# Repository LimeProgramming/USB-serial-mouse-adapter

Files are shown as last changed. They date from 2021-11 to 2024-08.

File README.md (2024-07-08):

# USB Serial Mouse Adapter
A USB to serial mouse adapter!
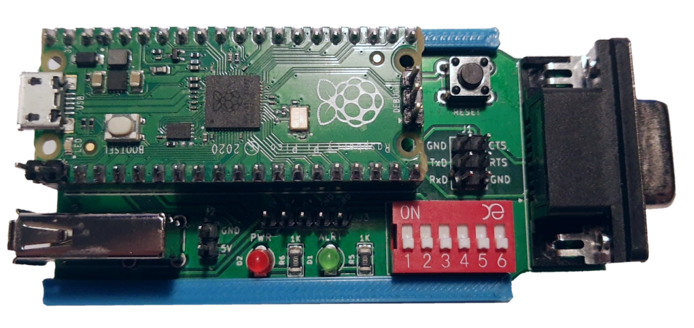
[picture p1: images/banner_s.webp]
ASSEMBLED_ADAPTER


## About
This project came about when I got my hands on an old 486 based PC. Having never really dipped my toes into retro computing, I didn't have an old serial mouse on hand. A quick eBay searched revealed that the decent ones cost a nice chunk of change that I didn't feel they were worth. Another search on Vogons revealed that some mad lads out there made active PS/2 to serial adapters using various micro controllers.  
Out of curiosity I examined how these worked and thought "Why can't I do this with a Pi Pico and USB mouse?" which kicked off this project. 

I hope it sparks your interest!
-Lime

## Features
With this adapter you can convert a modern native USB mouse to a classic serial mouse. That's right, native USB! No cheating by secretly using PS/2 compatible mice.
Want to use an optical mouse on a 386 running Wolfenstein 3D? Well now you can! Want to use a wireless optical mouse on a 486 running Doom? Well you might be able to! (depending on the mouse)

**Supported Protocols:**
- Microsoft Two Button
- Logitech Three Button
- Microsoft Wheel

**Unsupported Protocols: (May change based on demand)**
- Mousesystems
- Sun
- MM

### KVM:
Support for use on KVMs has been added as of version 1.1.1. 
It works fine on my **one**, startech branded, KVM that I have test with. Given that TinyUSB is a bit picky, your results may vary.

## PCBs
There are two variants of the PCB available in the KiCad folder, Phat and Slim for your preference. The main circuit for both PCBs is the same so the firmware package will work on both PCBs. A full BOM for LCSC (except for header pins) is available in the Phat folder: [LCSC BOM](https://raw.githubusercontent.com/LimeProgramming/USB-serial-mouse-adapter/main/KiCad/Phat/BOM_LCSC.xls). For the Slim build you can omit the dip switches and reset switch (you will have to source an appropriate SMD reset switch).

### Building a PCB:

#### MAX232/3232 voltage selection:
The PCB has a jumper to select between 3.3v and 5v for the MAX chip. 
- If you're using a MAX232 then bridge 5v to the center pin and install all the resistors. The part listed in the [BOM](https://raw.githubusercontent.com/LimeProgramming/USB-serial-mouse-adapter/main/KiCad/Phat/BOM_LCSC.xls) is a MAX232 chip.
- If you're using a MAX3232 then bridge 3.3v to the center pin, bridge R4 and R3, and remove R1 and R2.

#### Board to Pico USB data connection:
The `TP2` and `TP3` testpoints on the board must be soldered to the corresponding `TP2` and `TP3` test points on the Pico, underneath the USB connector:

[Pico bottom TP2 and TP3 test points](images/Pico_bottom.png)

### Phat:
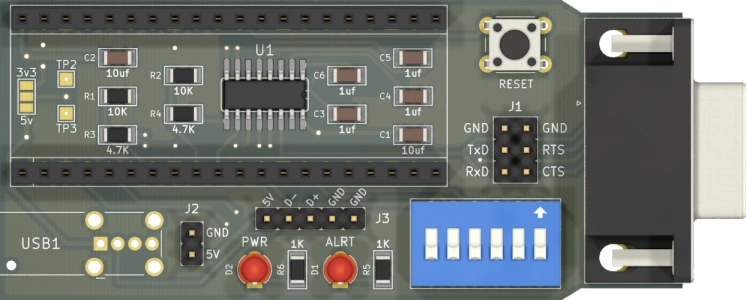
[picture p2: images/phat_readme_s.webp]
PHAT_PCB
[](https://raw.githubusercontent.com/LimeProgramming/USB-serial-mouse-adapter/main/images/phat_readme.png)

Also known as the original design.
This PCB is the version I had made with the mindset of it being the default/one and only. 
| Differences | Silkscreen | Description |
|:--:|:--:| :--:|
| Serial Pin Header | J1 | Intended to use with a serial breakout cable |
| USB Pin Header | J3 | Intended to be used with motherboard USB breakout cables |
| Dip Switches | SW1 | Quickly and easily configure the adapter |

#### Phat Cases:
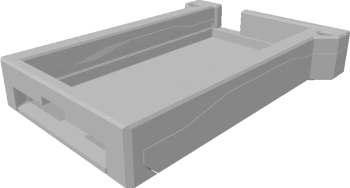
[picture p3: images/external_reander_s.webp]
externalcase
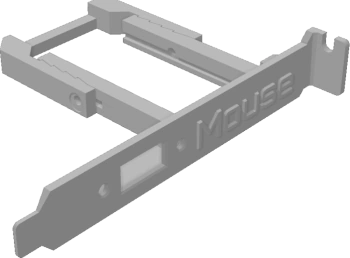
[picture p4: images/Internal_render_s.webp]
internalcase
[](https://raw.githubusercontent.com/LimeProgramming/USB-serial-mouse-adapter/main/images/external_reander.png)[](https://raw.githubusercontent.com/LimeProgramming/USB-serial-mouse-adapter/main/images/Internal_render.png)

### Slim:
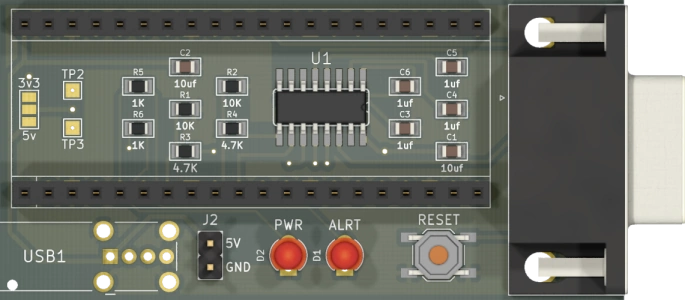
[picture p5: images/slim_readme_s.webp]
SLIM_PCB
[](https://raw.githubusercontent.com/LimeProgramming/USB-serial-mouse-adapter/main/images/slim_readme.png)

Made for people be require the adapter to be as small as possible. Not much wider than the serial port itself. 

## Powering the device
### MicroUSB:
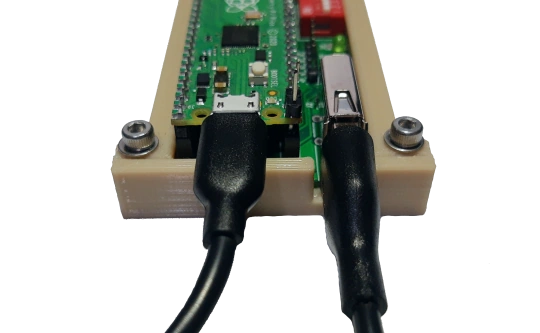
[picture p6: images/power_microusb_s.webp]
POWERING_MICROUSB
[](https://raw.githubusercontent.com/LimeProgramming/USB-serial-mouse-adapter/main/images/power_microusb.png)
The easiest way to power the device would be to use the Pico's micro USB port. Be sure to use a USB power only cable or a wall power adapter otherwise it won't pick up the mouse.

**PLEASE NOTE:** Some "power only" USB cables have the data lines shorted together. You can test if this is the case by plugging the cable into the Pico and using a meter to check for continuity between `TP2` and `TP3` on the Pico. If there is continuity you have a cable like this. Cut the data lines on a normal USB cable as an option.
<br clear="left"/>

### Power-In Header:
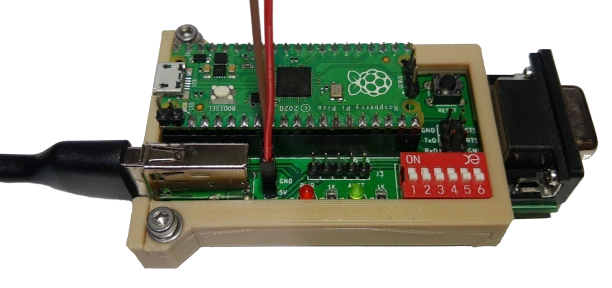
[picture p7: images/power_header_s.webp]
POWERING_HEADER
[](https://raw.githubusercontent.com/LimeProgramming/USB-serial-mouse-adapter/main/images/power_header.png)
Both the Phat and Slim PCB's feature an 5 volt power in header. You can use this creatively to power the adapter, even from the PC itself perhaps? Personally I'm connecting it to a wall power supply to give a more secure connection than MicroUSB.
<br clear="left"/>

### Other ways:
There is nothing stopping you from powering the device using a powered OTG cable or a hacked up USB extension lead. The device itself needs about 100 milliamps so as long as you get it that power, it'll run away happily!

## Configuration

The adapter has quite a few settings available and these settings are stored on micro controllers flash memory. 
It will remember your settings between uses and the same settings carry between different computers and even firmware upgrades (unless otherwise state in a changes log)

There are two primary ways of editing the settings of the USB-2-232

### Headers
The phat variant of the PCB includes headers in either of the form of dip switches or jumper headers. While not super configurable they do give quick access to some handy settings. The headers can be set while the micro controller is on with changes being applied in real-time or they can be set while the micro controller is off with changes being applied next time the controller is booted.

| Num | Setting |
|:--:|:--:|
| 1 | Three Button Logitech Protocol |
| 2 | MS Wheel Protocol |
| 3 | 75% Mouse Travel Modifier / Dip 3 + 4 for 25% |
| 4 | 50% Mouse Travel Modifier / Dip 3 + 4 for 25% |
| 5 | 7N2|
| 6 | 19200 Baud Rate|

### Serial Terminal
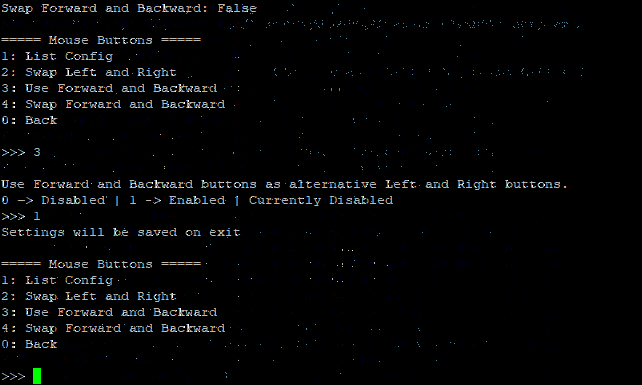
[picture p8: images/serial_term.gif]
serial terminal gif


Both the phat and slim variants of the PCB support being configured via serial terminal. The serial terminal allows for more advanced configuration of the mouse adapter. Any additional settings added in a software update will be available here.
The serial terminal has been translated to German, images available in both German and English as default langauge.  

### Serial Terminal Options
+ Mouse Travel
    + List Config
            | List the current mouse travel settings
    + XY Travel 
            | XY mouse travel modifier 1% -> 200%
    + X Travel
             | X (Left and Right) mouse travel modifier 1% -> 200%
    + Y Travel 
            | Y ( Up and Down) mouse travel modifier 1% -> 200%
    + Invert X
            | Invert X (Left and Right) mouse movement.
    + Invert Y
            | Invert Y (Up and Down) mouse movement.
    + Movement Type
            | Set Movement Type. USB mice talk faster than serial mice, movement type decides what to do with the backlog between serial mouse updates.
        + Additive: 
                | Sum the mouse movement (Sensitive)
        + Average
                | Avg the mouse movement  (Insensitive)
        + Coast 
                | Send the mouse movement incrementally (Slippy)
    + Cosine Smoothing
            | Makes the cursor proportionally less sensitive at high speeds, leaving the movement mostly one to one at low speeds

+ Mouse Buttons
    + List Config
        | List the current mouse button settings
    + Swap Left and Right
        | Swap the left and right mouse buttons
    + Use Forward and Backward
        | Use the mouse forward and back buttons as alternative left and right buttons
    + Swap Forward and Backward
        | Swap forward and back buttons if they are being used as alternative left and right buttons
+ Serial Settings
    + List Config
        | List the current serial settings
    + Format
        | One stop bit (7N1) or two stop bits (7N2) 
    + Baud Rate
        | 1200 2400 4800 9600 19200 Baud Rates. Note you will need compatible mouse drivers.
     + Mouse Type
     | Microsoft 2 Button, Logitech Three Button or Microsoft Wheel mouse. Note: You may need to reconfigure your mouse driver upon change.
+ Firmware
    + Information | Information about the firmware
    + Language | Set the language of the settings terminal
    + Reset | Reset mouse settings back to default
    + List Default Settings | List the default settings of the adapter
+ Exit
    + Return to mouse mode

### Accessing the terminal
You can access the serial terminal in one of two ways:

#### Method 1: Serial Terminal Emulator
You can open a serial terminal emulator (like kermit) on the computer you have the mouse connected to, connect to the same com port the mouse driver is using and press the enter key.
```
Baud Rate: User Set
Data Bits: 7
Stop Bits: User Set
Parity: None
Flow Control: None
```
#### Method 2: USB to TTL
You can also connect the unused UART of the Pi Pico with a cheap USB to TTL device or even another Pico running the picoprobe firmware. Open your favorite serial terminal emulator (like putty) connect to the TTL device and tap the enter key. 
```
Baud Rate: 115200
Data Bits: 8
Stop Bits: 1
Parity: None
Flow Control: None
```
Connecting to the adapter in this way will allow you to change settings regardless of the adapter being connected to a PC or not. 
The unused UART of the pico can be accessed from the top two pins between the full size USB port of the PCB and the micro USB port of the Pico.

### Resetting the adapter
Forgot your settings and can't get the adapter working? Don't worry.
There are three different ways to reset the adapter:

#### --- Serial Terminal
As written above, you can reset the adapter back to default settings from the terminal. You can connect to the unused UART of the pico regardless of the settings of the mouse. 

#### --- Small Flat Head Screwdriver
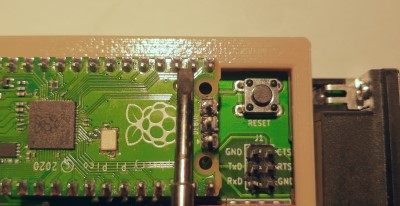
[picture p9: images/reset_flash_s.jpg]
RESETTING_FLASH
[](https://raw.githubusercontent.com/LimeProgramming/USB-serial-mouse-adapter/main/images/reset_flash.jpg)

**How To:**
1. Press a small flat head into the position shown above.
2. Power on the adapter and the Picos built-in LED will glow solid.
3. Hold the flat head in position for two or three seconds for the Picos LED to start blinking.
4. Once it is blinking, you can let go of the GPIO and press the reset button.
5. The adapter will boot up with default settings.
#### --- Nuke UF2
**How To:**
1. Download the [flash_nuke.uf2](https://datasheets.raspberrypi.com/soft/flash_nuke.uf2) file.
2. Connect the adapter to your PC using the microusb port built into the Pi Pico.
3. Hold Reset, then bootsel, then release reset then bootsel. This will make the Pico appear as a removable storage device. 
4. Drag the flash_nuke.uf2 file to the storage device. This will reset the flash the on the Pi Pico.
5. The Pico should reboot on its own and show up as a removable storage device again. If it doesn't, tap the reset button.
6. Download the latest firmware and drag that UF2 file to the storage device.
7. The adapter will boot up with default settings.

# Compiling the Firmware
The default mouse settings can be edited in `default_config.h` prior to compilation. You can use this to set the mouses default settings for your own configuration. 

The build environment is a normal PicoSDK setup, there are several guides out the for both Linux and Windows.  From experience the setup is easier in Linux. However there is one important thing you need to know:

**PicoSDK Version 1.5.1**
Previous Versions of this project required a customized version of TinyUSB, since then TinyUSB has implemented improved USB HUB and Hosting functions so the customized TinyUSB is no longer required. 
However, TinyUSB version 16 is recommended for the scroll wheel to work more reliably. 

# Known Issues
**USB Hubs**
Due to the pico having a USB 1.1 host or TinyUSB not using hubs correctly, this project struggles with hub compatibility. 
A hub which should work but I have not texted can be found here: https://www.olimex.com/Products/USB-Modules/USB-NeoHub/open-source-hardware 

Personally I use an amazon basics 4 port USB2.0 hub and it works perfectly.

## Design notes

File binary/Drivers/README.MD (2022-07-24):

# Modified Mouse Drivers
Modified serial mouse drivers which support higher baud rates.

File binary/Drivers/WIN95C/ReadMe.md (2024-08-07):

# Windows 95 
### Driver version: 4.0.0.950
**Supported Baud rates**
 - 1200
 - 2400
 - 4800
 - 9600
 - 19200
 
**How to install:**
 1. Drop VMOUSE.VXD of your desired baud rate to the following folder c:\windows\system\vmm32.
 2. Reboot and set your serial mouse adapter to your desired baud rate.
 
**Important**
To change the VMOUSE.VXD file for another speed you'll need to use a bootdisk of some kind. Not sure if DOS mode will work.

Enjoy.

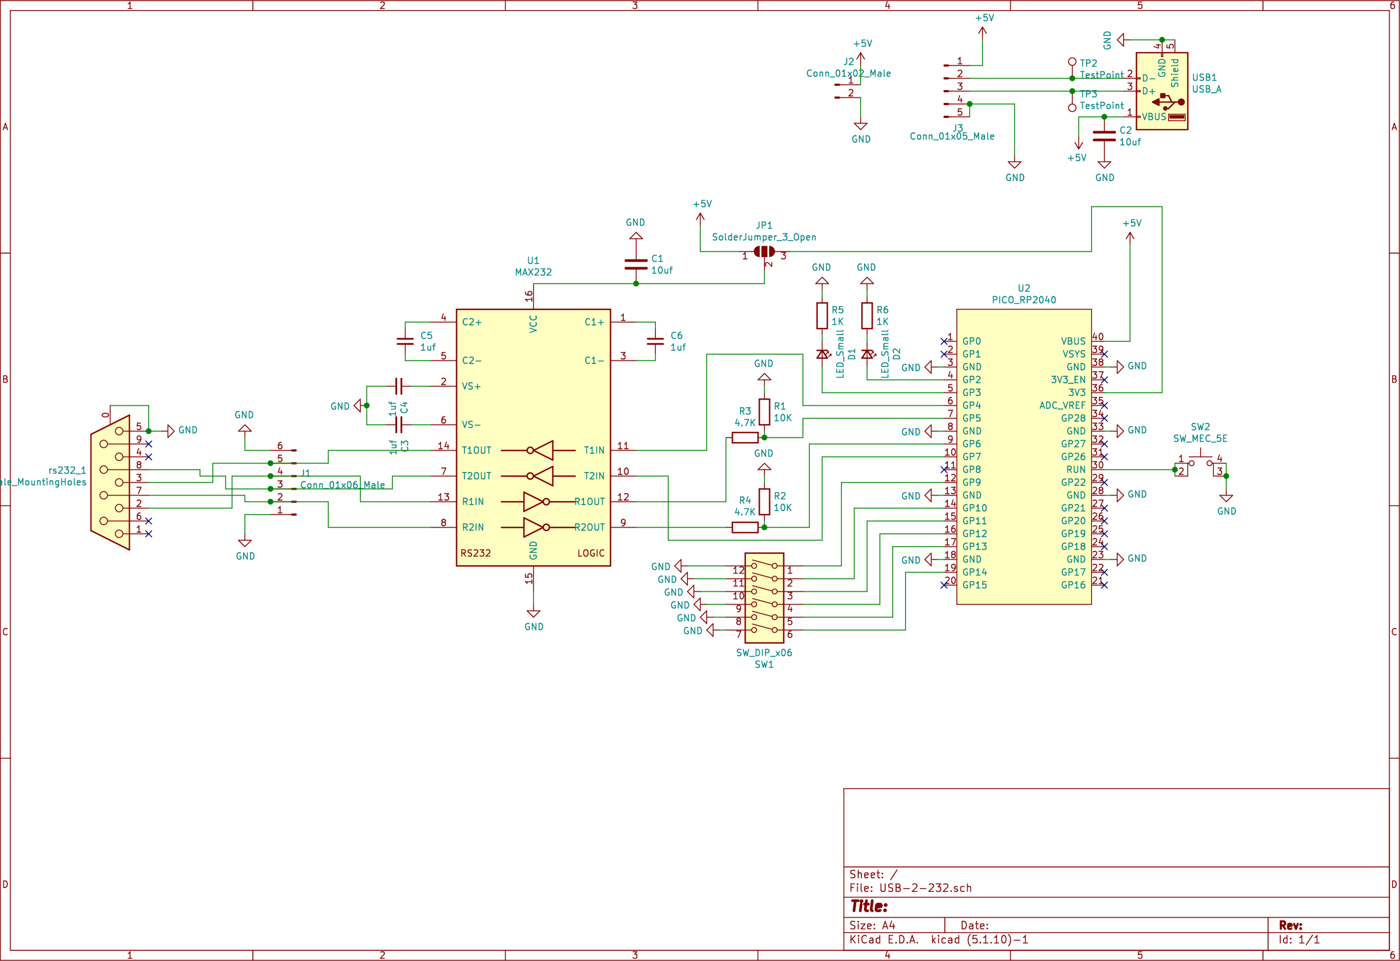
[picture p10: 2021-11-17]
images/Schematic.png

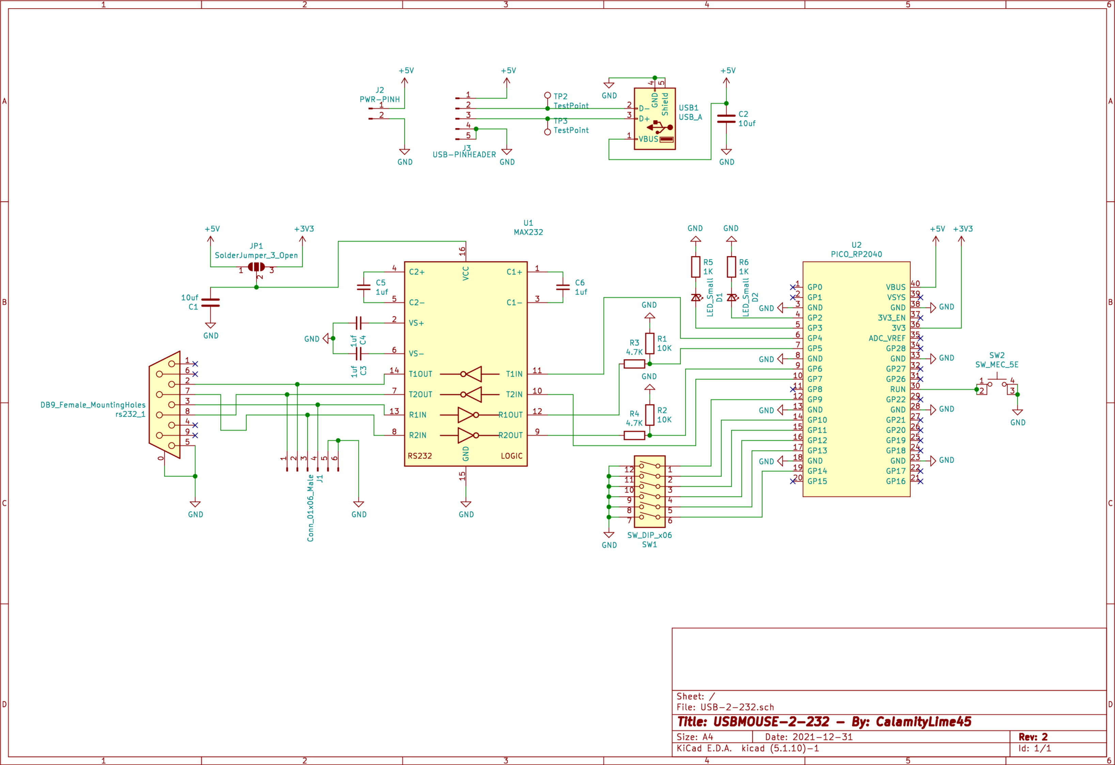
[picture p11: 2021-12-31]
KiCad/Phat/images/Schematic.jpg

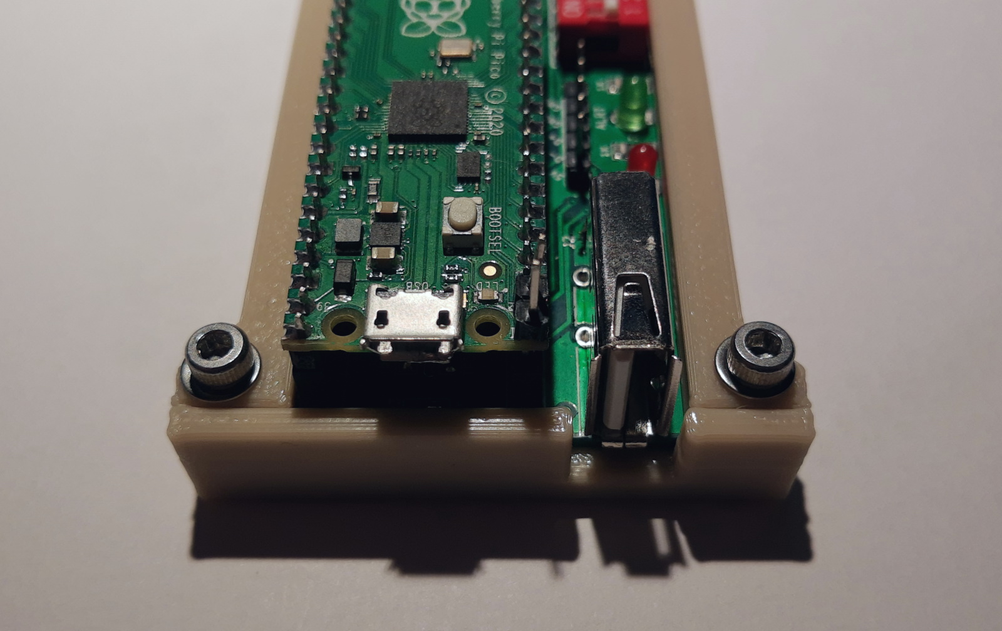
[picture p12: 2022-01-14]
images/Case-External-1.jpg

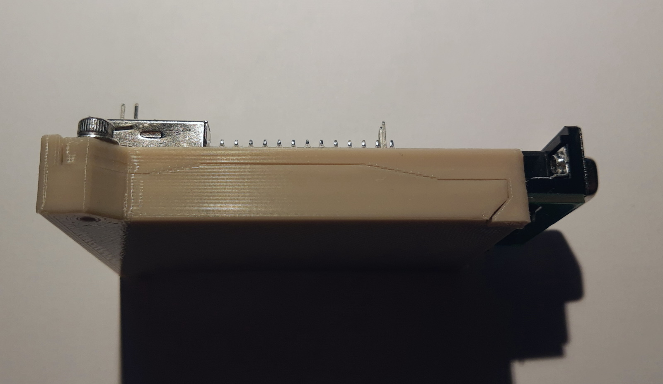
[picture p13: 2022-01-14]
images/Case-External-4.jpg

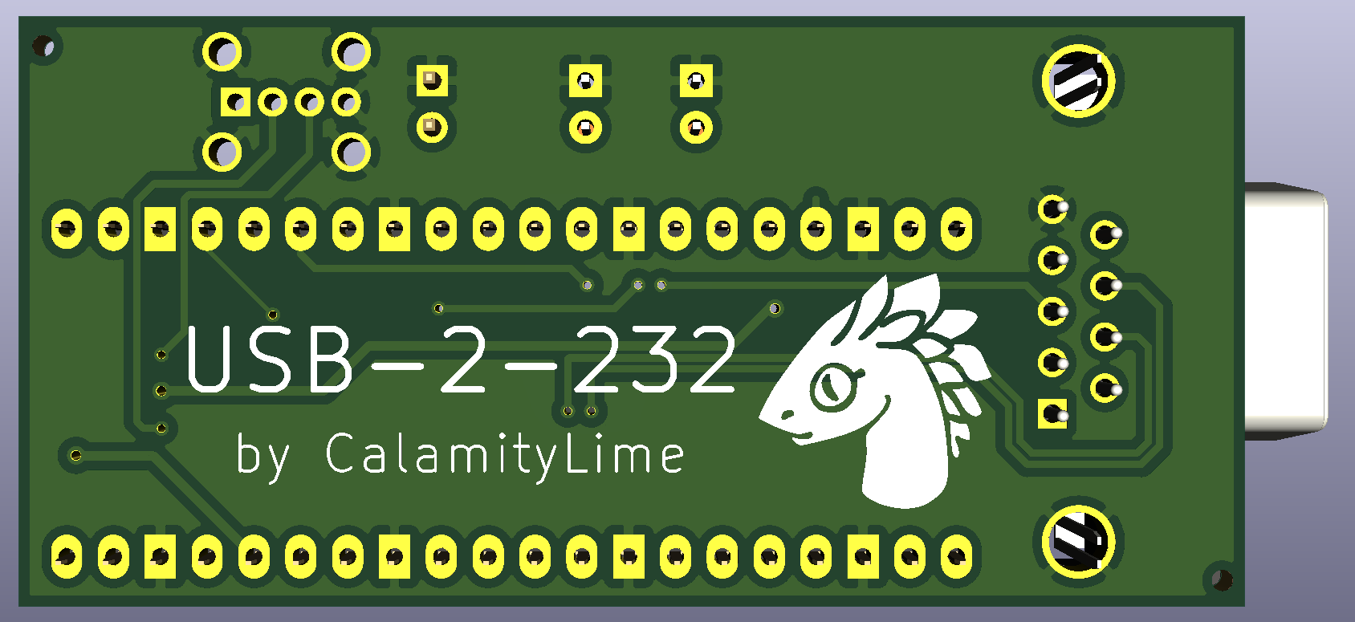
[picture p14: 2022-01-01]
KiCad/Slim/images/render_back.PNG

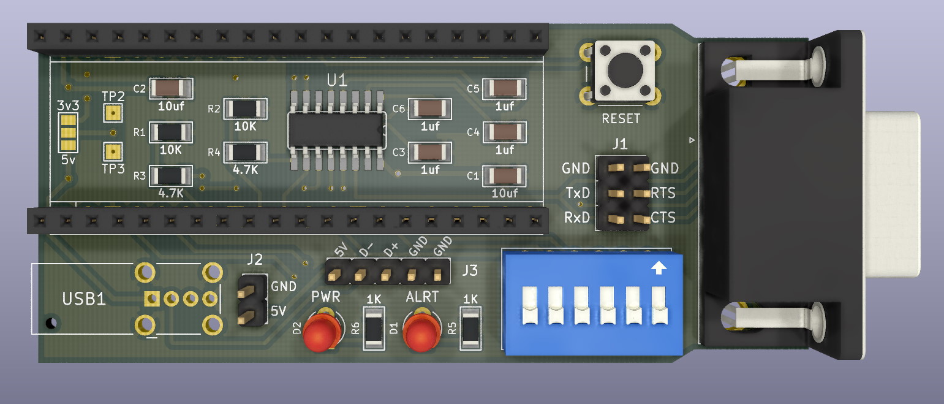
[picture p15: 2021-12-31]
KiCad/Phat/images/render_front.jpg

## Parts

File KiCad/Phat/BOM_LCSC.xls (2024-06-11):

LCSC Part Number | Manufacture Part Number | Manufacturer | Customer NO. | Package | Description | RoHS | Order Qty. | Min\Mult Order Qty.
C13585 | CL31A106KBHNNNE | Samsung Electro-Mechanics |  | 1206 | 50V 10uF X5R Â±10% 1206 Multilayer Ceramic Capacitors MLCC - SMD/SMT ROHS | YES | 20 | 20\20
C1848 | CL31B105KBHNNNE | Samsung Electro-Mechanics |  | 1206 | 50V 1uF X7R Â±10% 1206 Multilayer Ceramic Capacitors MLCC - SMD/SMT ROHS | YES | 50 | 50\50
C17902 | 1206W4F1002T5E | UNI-ROYAL(Uniroyal Elec) |  | 1206 | 250mW Thick Film Resistors 200V Â±100ppm/â„ƒ Â±1% 10kÎ© 1206 Chip Resistor - Surface Mount ROHS | YES | 100 | 100\100
C17936 | 1206W4F4701T5E | UNI-ROYAL(Uniroyal Elec) |  | 1206 | 250mW Thick Film Resistors 200V Â±100ppm/â„ƒ Â±1% 4.7kÎ© 1206 Chip Resistor - Surface Mount ROHS | YES | 100 | 100\100
C4410 | 1206W4F1001T5E | UNI-ROYAL(Uniroyal Elec) |  | 1206 | 250mW Thick Film Resistors 200V Â±1% 1kÎ© 1206 Chip Resistor - Surface Mount ROHS | YES | 100 | 100\100
C26860 | MAX232ESE+T | Analog Devices Inc./Maxim Integrated |  | SOIC-16 | 120Kbps transceiver 2/2 SOIC-16 RS232 ICs ROHS | YES | 10 | 1\1
C141882 | D-DMR009PF-D002 | Ckmtw(Shenzhen Cankemeng) |  | Push-Pull | 9P Female D-Sub Right-Angle 2 3A -50â„ƒ~+105â„ƒ Push-Pull D-Sub / VGA connector ROHS | YES | 10 | 5\5
C962227 | KH-BM2.54-6P | Shenzhen Kinghelm Elec |  | Plugin | 6Bit 24V Red 100mA 2千次 Slide (Standard),凸起式 Plugin DIP Switches ROHS | YES | 7 | 7\7
C26235 | USB-AF | Jing Extension of the Electronic Co. |  | Plugin | USB 2.0 1 4P Female Type-A Plugin USB Connectors ROHS | YES | 5 | 5\5
C85161 | 204-10SYGD/S530-E3 | Everlight Elec |  | Plugin,D=3mm | Green-yellow 3mmåœ†å½¢ç ¯å¤´ Plugin,D=3mm Light Emitting Diodes (LED) ROHS | YES | 20 | 20\20
C330748 | TJ-L3FYTGHRMBCSFLC4R-A5 | TOGIALED |  | Plugin,D=3mm | Red 3mmåœ†å½¢ç ¯å¤´ Plugin,D=3mm Light Emitting Diodes (LED) ROHS | YES | 20 | 20\20
C5274846 | YTS1R0012DBT00 | YIYUAN |  | Plugin,6x6mm | 6mm 6mm 50mA Round Button Straight SPST 6mm 250gf 12V Plugin,6x6mm Tactile Switches ROHS | YES | 20 | 20\20

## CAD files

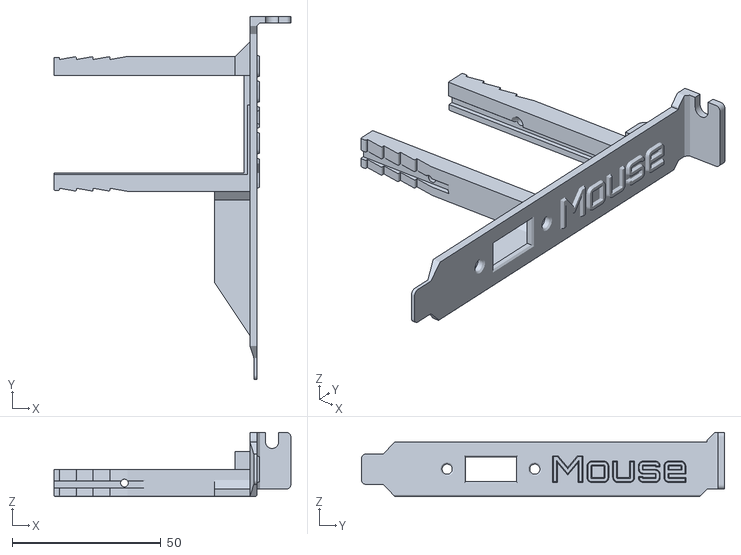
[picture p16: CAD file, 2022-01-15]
cases/Phat Board/Internal/Case-Internal-Sled.stl
79.7 x 122.2 x 21.6

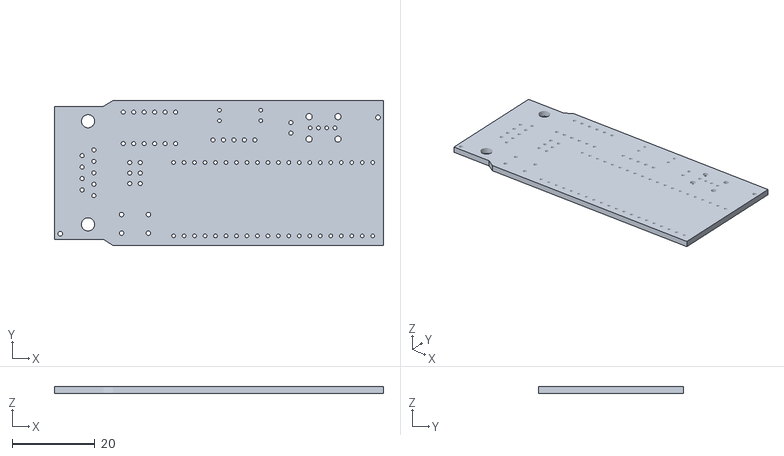
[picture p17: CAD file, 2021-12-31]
KiCad/Phat/USB-2-232-USB-2-232Pcb_1509.stl
79.7 x 35.1 x 1.60

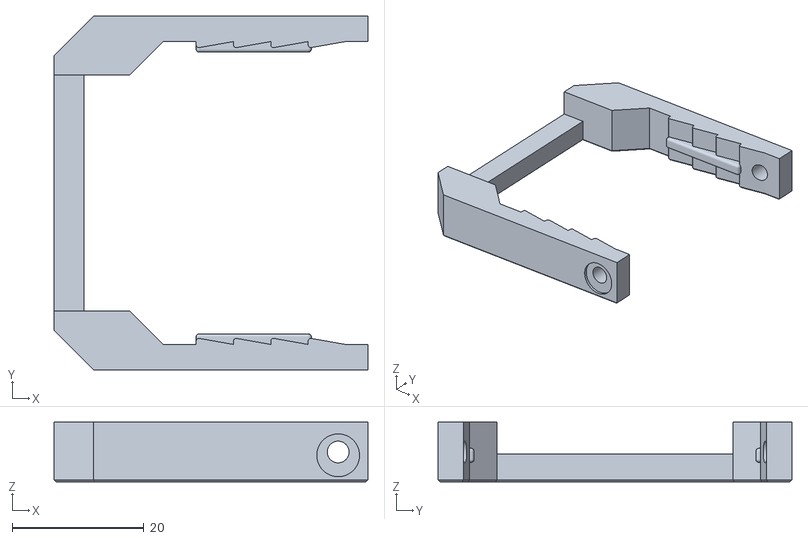
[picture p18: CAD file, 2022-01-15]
cases/Phat Board/Internal/Case-Internal-Lid.stl
47.6 x 53.8 x 9.11

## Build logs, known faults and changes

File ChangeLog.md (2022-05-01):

# Change Log

## Version 1.0.0
Initial Release.

## Version 1.1.1
- Added KVM and USB hub support
- Added different mouse movement types
- Added "cosine mouse smoothing"
- Small bug fixes
- Latest version of the Pico-SDK
- Latest but modified version of TinyUSB

## Version 1.2.2

- Modified terminal code to be easier to translate.
- German language translation added to serial terminal.
- Multi-core Processing. The Pi Pico has two cores baked into it so might as well use them. The second core is currently dedicated to transmitting the serial mouse data over UART and the first core is dedicated to handing the USB mouse, plus the serial terminal. This should keep the report rate consistent while keeping lag to a minimum.
- Flash wear leveling for saving configuration. Should extend the life of the Pico 200 fold.
- Added Support for 19200 baud rate.
- Changed the Dip Switch 6 to toggle between 19200 and 1200 baud rates.
- PWR LED now flashes while the adapter is in serial terminal mode.
- While adapter is in serial terminal mode changes to the dip-switches are ignored. This was an easy way to ruin your day before!
- Changed how Coasting movement type worked. Should feel the same but work more consistently.

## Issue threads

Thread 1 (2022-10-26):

Cant make it work

shaeon, 2022-10-26:
First of all, thank you for the project, I think it's amazing.

I had order some boards from China with the components and the rest of things I bought by internet without problems.

The first problem was that in the readme there is no documentation about the soldering point to choose 3.3V or 5V.  Looking at the schematic and some pictures I thought I should connect 5V to the center pin. That finally let me access to serial terminal.

The problem is that I can't get the mouse to work. I have tried on modern and old computers, Even I got a db9 serial mouse that works in all computers but the usb-serial-mouser-adapter doesn't work.

The only thing was that the first time I plugged it without the soldering point, but I don't think it was damaged or anything. Maybe I'm wrong and need to solder to the 3.3V and I fried a pi pico.

I did the following test, I opened a terminal with my real serial mouse and at the top when I move the mouse I get information (strange chars mark with red line). If I swap real mouse to the usb-to-serial converter (powered by a wall charger) I get nothing on screen, but if I invoke the menu it does come up.

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

What could it be?

LimeProgramming, 2022-10-26:
Ah, I had to re-read the read-me. I must have completely forgotten about the jumper.

It was very much just an early idea that stuck around. The jumper is for the max232. If you're using a max3232 then you bridge 3.3v to the center pin and bridge R4 and R3, and remove R1 and R2 (This was my first real PCB and it made sense to me at the time to do it that way)
If you're using a max232 then you bridge 5v to the center pin and install all the resistors.

I made it that way because technically using a max232 is out of spec and it should use a max3232 however the max3232 costs more, is potentially less compatible with host machines. and the basic part and cheaper max232 from JLC works just fine and is within tolerances.

Due to changes in the firmware the ALRT LED is really a mouse LED. It should light up when a usb mouse in connected to it. If it doesn't that means something else is on the USB line. In testing with others, usb wall power bricks connected to the microusb port can stop the pico from picking up the mouse.

You can solve this by a few ways:
- Using a USB brick that doesn't have data connections
- Using a USB cable that doesn't have data connections, (mine didn't, it was supposed to but it seems that they were broken) IF you're feeling up for it, you can cut into a usb cable gently and just cut the white and blue wires inside it. Sometimes really cheap ones for charging phones lack the data lines.
- Powering it via the pin headers.

I also believe that you can use an USB OTG with the extra connection for power. I believe so, I haven't used one myself.

Sorry about that. I never thought at the time about this issue. I have been working on a new edition of this board that's powered differently to fix this issues. I just never backported it since I didn't think people were interested in this project.

Also, those weird characters on top of putty print out, that's just the mouse movement data. It;s what your driver usually see's

I hope that helps.
If you're interested, there is a thread on vogons about this project that might help. I've documented a lot there while working on this, if something is missing from the readme here, it would be somewhere there.
https://www.vogons.org/viewtopic.php?f=46&t=84280

-Lime

shaeon, 2022-10-27:
I did order to JLC with your gerbers, bom list, all! It was so easy :)

4 person (some friends) ask me about this adapter, because the serial mouse became be so difficult to get. I discovery what's wrong looking scheme and photos at vogons.org web.

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

I didn't solder wires between usb D+ D- line from pcb to pi pico. Again i didn't read that on readme. I'll test it tomorrow because because I have board at work. I'll tell you them.

Thanks for your help / support. :)

LimeProgramming, 2022-10-27:
Wow I forgot about those wires myself.

I'm going to have to update the read me with an assembly section.
Again, Sorry about that. I also have a firmware update that I have to push out but I'm messing with drivers at the moment. You might have read on Vogons that I want to get higher baud rates working on win95, I don't know how possible that actually is though but we'll see. There has also been an update to TinyUSB and it behaves much nicer with hubs and multiple devices present (most of the time anyway)

You just have to solder TP2 on the PCB to TP2 of the pico, TP3 of the PCB to TP3 of the pico.

Let me know what you use this for, I'm very curious what people would want these for.
-Lime

shaeon, 2022-11-02:
Hi Lime!

I solder the two D-,D+ usb lines but i cant still make it works. I think i'm loosing something. Even I tried do nuked and after load again firmware 1.3.2. Maybe i need try another version?

I tried: Two different boards with 3 different usb mouses, in 3 different computer, but i cant get light in "alarm" light when i plug mouse, so I think this is the big problem.

My boards come with almost solders from JLC (even cheap max232). I just got your gerbers and bom and upload. I test line from usb with tester and i have line in pinheader J3, 5V and GND.

What i can test it more?

We'll use in old computer, because old serial mouse became more hard to make it work.

Best Regards.

LimeProgramming, 2022-11-02:
I tried nuking one of my boards, loaded the firmware 1.3.2, plugged in a usb mouse and it worked.
I cut open the usb cable to cut the white and green wires for reasons I said in my first reply.

You are getting a power LED aswell yeah? it's not a case of just soldering in the leds the wrong way. The power led comes on when the device has power and it blinks to tell you it's in serial terminal mode.

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

LimeProgramming, 2022-11-02:
As you can see, the ARLT led lit up without the serial port being connected to anything.

The mouse is a standard microsoft mouse and this adapter has worked with every usb mouse I tried.

Does this image help at all?

You can ignore the black jumper above the green led, I didn't notice it before taking the picture. It's not doing anything.

shaeon, 2023-02-20:
I did a lot of test, i think maybe my wire is thin but change mouse (one that work on mist) and power by duponts work perfect! :)

I'm sorry be so late answer you. Thanks for your support.

I close this issue. (very happy!)

Closed 2023-02-20.

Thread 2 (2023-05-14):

BOM in plain text for both PCBs?

KenjiUmino, 2023-05-14:
I would like to build the slim version of this adapter, but I could not find a bill of materials list - until I looked into the KiCad files for the phat PCB and found a "BOM_JLCSMT.xls" that I had to download before I could view it.

This file seems to be for the slim PCB as it does not include the switch block.

It would be nice to have a BOM for both PCBs in plain text so it is viewable from the webbrowser.

LimeProgramming, 2023-05-16:
Hello there

The slim PCB doesn't have the switch block at all. Honestly even though at first I was very amendment about the switch block being a requirement for ease of use, I use the terminal to configure the adapter.

Fair point. I saved the BOM and CPL in normal excel file formats just to stop a popup when I saved the file in excel.
I should be able to just add a readme in the folders.

I hope you enjoy the adapter.

KenjiUmino, 2023-06-04:
Hi Lime,

thanks a bunch for looking into it

> I saved the BOM and CPL in normal excel file formats just to stop a popup when I saved the file in excel.
> I should be able to just add a readme in the folders.

Thanks for looking into it - I have not finished the adapter yet, which might be a good thing, as I found out I might get it done cheaper than expected.

I originally planned to order the slim PCB at some PCB place, but in another futile attempt to organize the mancave, I found out that I have way too many of these small green proto boards than I know what to do with and it looks like they are just big enough to fit everything (including the jumpers for configuration) while the whole thing would be about the same size as a slim PCB.

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

Closed 2023-06-04.

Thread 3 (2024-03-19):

PCBWay details

Fachher, 2024-03-19:
Hi. I would like to thank you for your great work. Could you please provide all information required by PCBWay, so that they can make it.

Number of Layers, Dimension, FR4-TG, Thickness, Hole size, Surface finish, Finished copper.

https://www.pcbway.com/orderonline.aspx

Thank you in advance for your help.

sweetlilmre, 2024-06-24:
I'm pretty sure that if you just upload the gerbers and use the defaults you'll be fine. Are you wanting PCBWay to do the assembly as well? My suggestion would be to use JLC for the boards and LCSC for parts, it's much more cost effective if you build it yourself.

Fachher, 2024-06-24:
Hi @sweetlilmre thank you for your answer. Adam recommended JLC to me as well. Boards have been manufactured in the meantime. If I find the time, I will try to assemble the components on the board. Btw would it have been possible for JLC to assemble the board for me?

sweetlilmre, 2024-06-24:
It would have, but not worth it in my opinion. With the 1206 footprint of the SMD components, soldering it yourself should be fairly easy. Only complex chip was the MAX232 but even that wasn't too bad.

LimeProgramming, 2024-06-25:
this board was meant to be hand soldered which is why i used very large components. I didn't know how the SMT services worked and I had enough to figure out in this project at the time.

and since it kinda looks like I just ignored this issue, they emailed me and I talked to them via email.

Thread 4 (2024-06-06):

LCSC / JLCPBC parts

sweetlilmre, 2024-06-06:
In #2 a user is asking for the complete BOM list, specifically required is the DB9, dip switch block, USB A socket.
Could you provide these? A full BOM with everything: LEDs etc would be appreciated.
I have looked at LCSC and found these part numbers which may work:

DB9: C141882
DIP Block: C5299507
USB Socket: C720524

LimeProgramming, 2024-06-08:
Parts your picked should work fine, but here's what I used.

DIP 9: C141882
USB socket: C26235
Dip block: C962227

LED's are LED's, pick your favourite colors and enjoy.

I feel like this project has gotten far more interest than I thought it would, especially in the last 2 or 3 weeks. Did something happen?

sweetlilmre, 2024-06-09:
Thanks for the confirmation. I ordered the parts I'd selected, so I'm glad to know they'll work!
As far as interest, I found the project after making some of necroware's PS2 to serial adapters and trying to improve the firmware by looking at other code. I have a feeling your project might have been mentioned on the PicoGUS discord some time back but can't be sure, so that might have spurred interest. At any rate, it's an awesome solution and I can't wait to build some boards, thank you!

LimeProgramming, 2024-06-09:
Ah I see.

fair enough so. Good luck with them. TinyUSB at least last I looked at it was a buggy mess, so the adapter is very picky with hubs and it doesn't like unplugging and replugging the usb mouse.

But it does work when it's working.

I did include modified serial mouse drivers for DOS in the repo, thought I had included the modded drivers for windows 9x as well but doesn't seem like I have, no idea where those have gone now. I remember trying to make a bootdisk that installed the drivers automatically and it worked fine for english installs but no other languages because it tried to find the version of windows you were using from the license file.

Still, thanks for the interest and enjoy.

Closed 2024-06-23.

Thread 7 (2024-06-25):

No Power To Mouse

oXL0C0Xo, 2024-06-25:
Hoping that someone here can help me. When plugging in a USB optical mouse (Intellimouse Optical USB), I haven't been able to get the laser on the mouse to light up no matter what I try.

I have tried different USB cables (about 15 of them), also powering the device via the 5v header straight from the power supply, nothing seems to get this mouse to light up.

I can access the serial configuration tool, so I know that it is connected. If I plug the mouse into my personal computer, it powers right up and I can use it, so I know that it is good.

I have used a max232, and the 5v bridge is in place.

The strange thing is that this is the second adapter I have built, as I was having the same issue with the previously built one.

Any Ideas would be greatly appreciated. Thanks!

sweetlilmre, 2024-06-25:
Have you soldered TP2 and TP3 on the board to the TP2/TP3 points on the Pico? I'm facing similar issues and trying to debug (I had the laser blinking, but only went stable after that, although the adapter is still not working). This closed issue has some detail: #1 

I have a pending PR to update the docs.

oXL0C0Xo, 2024-06-25:
I had not done that, but I just tried it and it doesn't seem to make a difference

oXL0C0Xo, 2024-06-25:
Some more information... if I have all of the switches set to "off" it detects the mouse when I boot, and loads the driver (the mouse still doesn't power up). If I then try to access the serial config using kermit, nothing comes up. If I then set switch 6 to "on", I can connect to the device config, and the power light starts flashing.

The weird thing is that if I leave switch 6 set to "on" and reboot the system, it no longer detects the mouse.

Regardless, I should be able to just plug this into a USB brick on the wall, and when I plug my mouse in it should power up without needing to be connected to a computer via serial correct?

sweetlilmre, 2024-06-25:
AFAIK yes, my mouse does power up. Maybe try another mouse if you have one available, and failing that I guess double check everything and use a meter to test voltages? Sorry I can't be more help. If I find something I'll ping back.

LimeProgramming, 2024-06-25:
sounds like the data lines are getting a bit of abuse here.

I should really backport an update to this PCB to just say "use this port for power"
Try either getting a really cheap power cable, use a breakout board or carefully cut open the cable you're using to power the pico and cut the green and white wires.

this issue stems from my own equipment being painfully cheap at the time I was making this so the usb cable i used to power the pico didn't have data wires.

Sorry about that.

oXL0C0Xo, 2024-06-25:
Curious though, because I am powering it from the 5v header on your PCB. Does it also require the pico to be powered independently?

LimeProgramming, 2024-06-25:
power went out. hey.

ahh no powering the device with 5v via the header should be fine. not sure whats going on so. TinyUSB is a picky *thing* to deal with, have you tried tapping the reset button and all that?
unplugging and replugging the mouse will cause tinyusb to crash and it likes to crash in a way that I couldn't figure out how to catch and handle.

I haven't had compatibility issues with any mouse I've tried, even my logitech g502 worked fine, unless you have a very unusual mouse, it should be okay. if the tp1 and tp2 wires are soldering in correctly

sweetlilmre, 2024-06-25:
Here I have 2 of 3 microsoft mice powering up but no activity. I cut open the USB cable only to confirm that it was indeed power only. I've shortened the tp1 and tp2 wires, still not working. I'll try another pico next to see if this is is a dud. 

Serial works and reports the mouse fine, so something is at least partially working.

oXL0C0Xo, 2024-06-25:
I’m attaching some pictures of my unit. As far as I can tell, everything is where it should be. I did try resetting and replugging and every switch configuration, but the issue remains.
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

oXL0C0Xo, 2024-06-25:
I am testing everywhere that I should have 5v, and I am getting it. I think that this must be a firmware issue, and it is just not initializing this mouse for some reason. The computer is detecting the mouse emulation, its the input that is not getting picked up by the PI. The mouse I am using is an "IntelliMouse Optical USB & PS/2 Compatible". If there is any more information that I can provide to help solve the issue, let me know.

LimeProgramming, 2024-06-25:
I'm not sure here.
The soldering looks good, the length of the tp wires _shouldn't_ matter too much because it's usb 1.1, in my own testing I had very long wires (maybe half a meter) and it still worked fine.

I have an MS basic usb mouse that I've tested on the device and it works fine. You're not using a hub are you? TinyUSB was really picky with hubs. I'd expect plugging and replugging to crash the device (blame tinyusb) If you want to try using a microusb OTG cable if you have one, plus the microusb into the pico and the mouse into the full sized usb port. The on board usb port is a more elaborate version of the same.

When the device has power and a serial connection it will present itself to the computer as a serial mouse and however if the usb mouse side isn't connected then it just won't report any data other than the type of mouse it is. the alrt light should light up when the usb mouse is connected and recognized properly.

Also the mouse "laser" should only turn on when tinyusb picks up that the mouse exists, there is a handshake performed before the mouse will light the laser. So the mouse can still get power and not light up. hmmm let me see if tinyusb has gotten an actually useful update.

sweetlilmre, 2024-06-25:
I'm going to:

- recheck all the soldering (just reflowed some resistors that were possibly marginal)
- try another pico
- try some more mice
- possibly recompile the firmware and use the onboard LED to blink at strategic points so I can see where the code is.

Laser turns on for 2 of 3 mice tested, no ALRT LED activity so far.

oXL0C0Xo, 2024-06-25:
Not using a USB hub, the mouse is plugged directly into the USB-2-232. I have never seen the ALRT light activate, nor the laser on my mouse ever turn on for even a second. I will see if I have an non-optical USB mouse to test also. Most of my USB mice are optical however, and all of them suffer the same issue. I really appreciate you looking into this!

oXL0C0Xo, 2024-06-25:
Just tried a bunch of other USB mice, all optical unfortunately, none of them worked. Also tried some PS/2 ball mice with a PS/2 to USB adapter...still nothing. Could there be a difference between our PI picos that is causing the issue? mines got a 2020 date on it, and I see a 2.20 on the back side, not sure if that is a version or what. This has got to be an issue with the firmware not detecting the mouse. I wish i was a software guy so I could dig in.
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
oXL0C0Xo, 2024-06-25:
so bad news for me, guess all the mice I plugged into that adapter died, with the exception of my razer mouse. They light up, but they no longer work. but i was able to plug my desktop mouse back into it and now it works!

LimeProgramming, 2024-06-25:
well, so good news and bad news there.

But at least you got the adapter working and an excuse to buy a pile of mice, hopefully the ps2 ones survived at least.

You're welcome.

oXL0C0Xo, 2024-06-25:
so far with my testing testing, it seems that none of my PS/2 mice were destroyed because the ps/2 to usb adapter is active and that was destroyed instead. =)

All USB mice are toast though

oXL0C0Xo, 2024-06-25:
USB port tester for the win!
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

LimeProgramming, 2024-06-25:
Nifty Gadget.

Sorry about the mice though.

oXL0C0Xo, 2024-06-25:
Worth it to sacrifice some mice for the greater good. Now maybe someone else wont make the mistake. Could potentially save more mice than died to make the discovery. Also worth it because I can guarantee that any time that I use one of those ports on a project, I'm going to test the pins before I plug anything in =)

oXL0C0Xo, 2024-06-25:
Now I'm curious if sweetlilmre is having the same issue....

oXL0C0Xo, 2024-06-26:
Are you able to access the configuration of the FW with Kermit through the serial port?

sweetlilmre, 2024-06-26:
I haven't tried that, though the mouse is detected via cutemouse on the DOS PC side, are you doing this via DOS and if so, could you post a link to Kermit?
I don't have a USB->RS232 Serial for my laptop handy so can't test on that (though I may have one in a box somewhere).

LimeProgramming, 2024-06-26:
Hello there.
https://www.kermitproject.org/msdoskermit/

I use DOS for this because windows seems to "lock" the serial port when
it's using it for a mouse but dos doesn't care. Tusb is painful to deal
with. There is a generic "i found a device" type event that you could try
to ríg up to figure out if the device is even a mouse but I've tested that
and it works as well as the "I found a mouse" event, it either works or it
doesn't.

Several times I was tempted to throw away the pico and use a teensy with
USB hosting since that software seems more reliable. One idea I looked into
would be rolling back to the launch pico sdk because they did make a very
minimal USB host lib that might work better for this but I couldn't find
that code when I looked for it. I don't know GitHub very well, perhaps you
might have better luck with it.

This was the pain of development "this looks right why isn't it working, oh
tinyusb doesn't work, wonderful" to be fair to it, it seems more geared
towards making USB devices instead of USB hosts, USB hosting really only
got work put into it when raspi used it as a lib.

Good luck.

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

oXL0C0Xo, 2024-06-26:
I'm assuming that if you unplug the actual mouse from the device, your system will still detect a mouse on the port where the USB-2-232 is plugged in to. That's because that portion of the circuit is probably working. Can you send a couple photos of your assembled adapter?

LimeProgramming, 2024-06-26:
Yeah the USB mouse side and serial mouse side are kinda independent, so
even if there is no USB mouse, it will still detect as a serial mouse to
the serial port of the computer.

I can when I get home from work, however I think it's the same one pictured
in the readme. I'm not sure what's left for PCbs I had ordered.

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

LimeProgramming, 2024-06-26:
I'm not sure about this version of the program but I know in the kbd
version, the serial mouse is handled by core 1 and everything else handled
by core 0, that kept the report rates consistent.

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

sweetlilmre, 2024-06-26:
@LimeProgramming and @oXL0C0Xo  I've found the issue.

The cable I was using was USB power only, but internally had the D+ and D- lines shorted. This was the same for another power only cable. I will make a PR for the README.md file suggesting that folks _DO NOT_ use a power only cable :) :) :)

LimeProgramming, 2024-06-26:
I think I'm just going to have to give in and update the PCB to have mini
USB for power and I suppose a diode for some protection.

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

sweetlilmre, 2024-06-26:
I think it's OK :) You've got the header for power and now that the "power only shorted data lines" thing is out of the way and can be documented it should be fine. I'm looking forward to finally being able to test this thing out and make some more!

LimeProgramming, 2024-06-26:
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

here's the little development setup I had. it's not much but it worked, a bit dusty now though

LimeProgramming, 2024-06-26:
you can see the traces around j are different and theres a little bodge wire but other then that, it's the same as the PCB posted in the repo

LimeProgramming, 2024-06-26:
Just gonna mark this as closed.

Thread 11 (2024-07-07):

Idea: Implement a usb hub?

LimeProgramming, 2024-07-07:
With some time having passed since I started this project, other people have come along and ran into similar issues.
Someone made a hub for their project which properly supports usb 2.0 devices on a USB 1.1 host device like the pi pico.

here's a link to that project
https://github.com/OLIMEX/USB-NeoHub/tree/main

the chip they use is the ch334S

Perhaps the CH334R would be small enough and missing pins we don't need anyway to be implemented into a PCB. LCSC part number: C4154405

Might be worth including.

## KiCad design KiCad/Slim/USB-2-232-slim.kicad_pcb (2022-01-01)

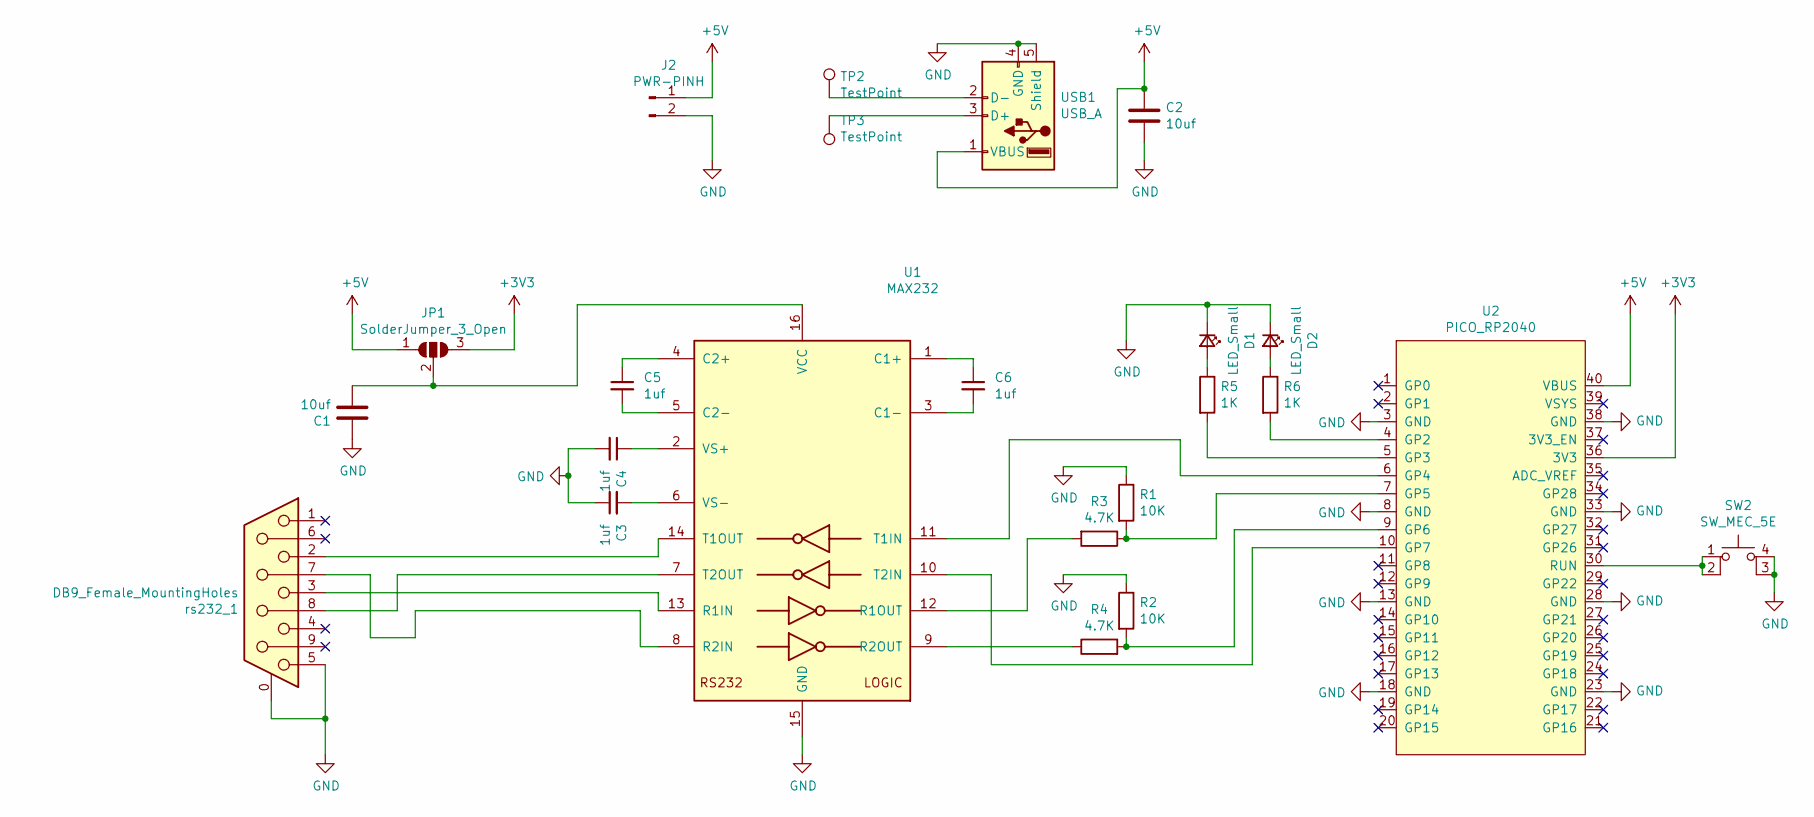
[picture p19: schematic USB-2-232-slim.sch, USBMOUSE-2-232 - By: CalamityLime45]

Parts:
C1, C2: 10uf; C_0805_2012Metric
C3, C4, C5, C6: 1uf; C_0805_2012Metric
D1, D2: LED_Small; LED_D3.0mm
J2: PWR-PINH; PinSocket_1x02_P2.54mm_Vertical
JP1: SolderJumper_3_Open; SolderJumper-3_P1.3mm_Open_Pad1.0x1.5mm_NumberLabels
R1, R2: 10K; R_0805_2012Metric
R3: 4.7K; R_0805_2012Metric_bridge
R4: 4.7K; R_0805_2012Metric_bridgeflip
R5, R6: 1K; R_0805_2012Metric
SW2: SW_MEC_5E; SMT_RESET_SW
TP2, TP3: TestPoint; TestPoint_Pad_1.5x1.5mm
U1: MAX232; max232_SMD
U2: PICO_RP2040; RPi_Pico_SMD_TH
USB1: USB_A; USB_A_Wuerth_614004134726_Horizontal
rs232_1: DB9_Female_MountingHoles; DSUB-9_Female_Horizontal_P2.77x2.84mm_EdgePinOffset7.70mm_H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

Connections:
+3V3: JP1.3 (B), U2.36 (3V3)
+5V: C2.1, J2.1, JP1.1 (A), U2.40 (VBUS), USB1.1 (VBUS)
GND: C1.1, C2.2, C3.1, C4.2, D1.1 (K), D2.1 (K), J2.2, R1.1, R2.1, SW2.3 (K), SW2.4 (A), U1.15 (GND), U2.3 (GND), U2.8 (GND), U2.13 (GND), U2.18 (GND), U2.23 (GND), U2.28 (GND), U2.33 (GND), U2.38 (GND), USB1.4 (GND), USB1.5 (Shield), rs232_1.0 (PAD), rs232_1.5
unnamed: C1.2, JP1.2 (C), U1.16 (VCC)
unnamed: C3.2, U1.6 (VS-)
unnamed: C4.1, U1.2 (VS+)
unnamed: C5.1, U1.4 (C2+)
unnamed: C5.2, U1.5 (C2-)
unnamed: C6.1, U1.1 (C1+)
unnamed: C6.2, U1.3 (C1-)
unnamed: D1.2 (A), R5.1
unnamed: D2.2 (A), R6.1
unnamed: R1.2, R3.1, U2.7 (GP5)
unnamed: R2.2, R4.2, U2.9 (GP6)
unnamed: R3.2, U1.12 (R1OUT)
unnamed: R4.1, U1.9 (R2OUT)
unnamed: R5.2, U2.5 (GP3)
unnamed: R6.2, U2.4 (GP2)
unnamed: SW2.1, SW2.2, U2.30 (RUN)
unnamed: TP2.1, USB1.2 (D-)
unnamed: TP3.1, USB1.3 (D+)
unnamed: U1.7 (T2OUT), rs232_1.8
unnamed: U1.8 (R2IN), rs232_1.7
unnamed: U1.10 (T2IN), U2.10 (GP7)
unnamed: U1.11 (T1IN), U2.6 (GP4)
unnamed: U1.13 (R1IN), rs232_1.3
unnamed: U1.14 (T1OUT), rs232_1.2

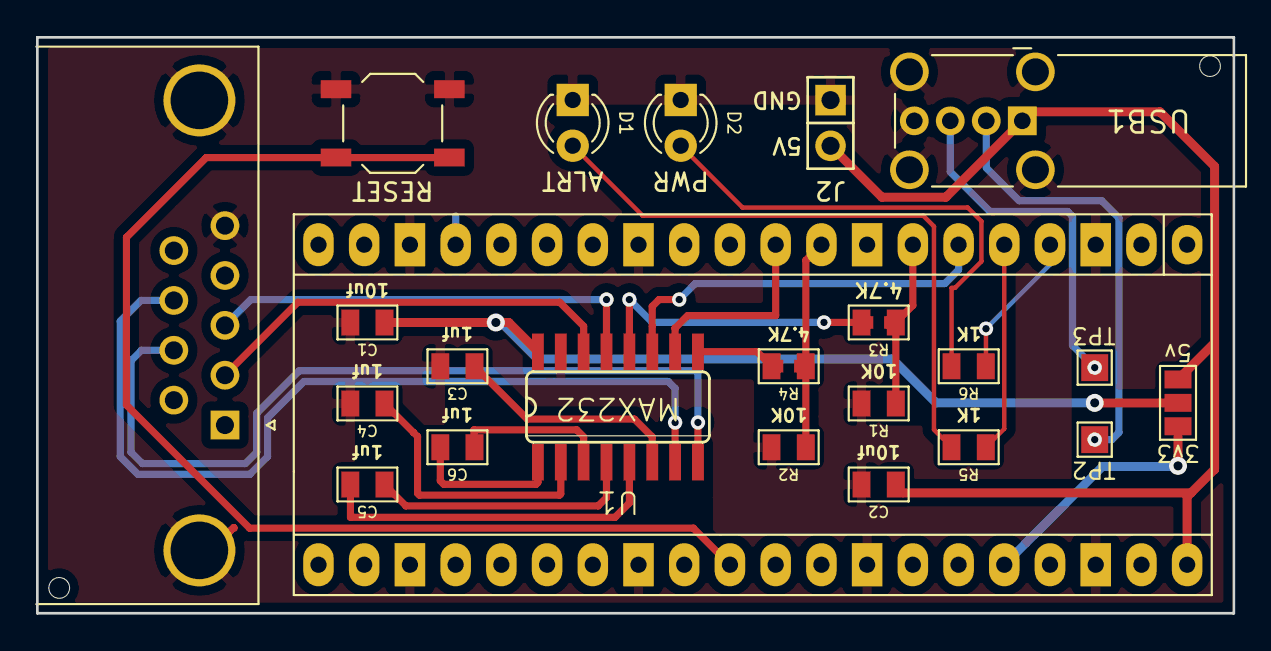
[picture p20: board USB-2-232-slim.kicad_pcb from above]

Board: 2 copper layers, 66.5 x 32.0 mm, 23 parts (0 on the bottom side), 27 nets.

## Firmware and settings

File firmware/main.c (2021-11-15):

#include "tusb.h"
#include <stdlib.h>
#include "bsp/board.h"
#include "hardware/gpio.h"
#include "hardware/uart.h"
#include "hardware/timer.h"
#include "hardware/divider.h"

#include "include/ctypes.h"
#include "include/utils.h"

#define DEBUG false          // Debug Flag for things

// Mouse Option Pins
#define MO_THREEBTN 9       // LOGITECH     | Dip Switch 1
#define MO_WHEEL 10         // MS Wheel     | Dip Switch 2
#define MO_75SPEED 11       // 75% speed    | Dip Switch 3  | With Dip 3 + 4 depressed will set mouse speed to 25%
#define MO_50SPEED 12       // 50% speed    | Dip Switch 4  | With Dip 3 + 4 depressed will set mouse speed to 25%
#define MO_7N2 13           // Compatibility with serial controllers which expect 8+1 bits format   | Dip Switch 5
#define MO_RESERVERD 14     // Reserved for future use  | Dip Switch 6

// LEDS 
#define LED_PWR 2
#define LED_ALERT 3

//UART stuff
#define UART_ID uart1       // Use UART1, keep UART0 for DEBUG printing
#define BAUD_RATE 1200      // Mouse Baud Rate. Default for Serial mice is 1200
#define UART_TX_PIN 4       // UART1 TX --> MAX232 pin 11
#define UART_RX_PIN 5       // UART1 RX --> MAX232 pin 12
#define UART_CTS_PIN 6      // CTS      --> MAX232 pin 9
#define UART_RTS_PIN 7      // RTS      --> MAX232 pin 10

/* ---------------------------------------------------------- */
/*  Numbers for Serial Speed and Delay times
    - Thanks to Aviancer for the numbers | https://github.com/Aviancer/amouse

    1200 baud (bits/s) is 133.333333333... bytes/s
    44.44.. updates per second with 3 bytes.
    33.25.. updates per second with 4 bytes.
    ~0.0075 seconds per byte, target time calculated for 4 bytes.

    SERIALDELAY = (((7500 * (BAUD_RATE / 1200)) * NumberOfBytes) + TXWIGGLEROOM )
/* ---------------------------------------------------------- */

static int32_t TXWIGGLEROOM    = 0; // This is for adding a bit of padding to the serial delays, shouldn't be needed but some controllers are awkward.
//static absolute_time_t txtimer_target;      // Actual time between the sending of serial packets, calculated on startup.
static int32_t SERIALDELAY_1B;      // One Byte Delay Time, calculated on startup.
static int32_t SERIALDELAY_3B;      // Three Byte Delay Time, calculated on startup.
static int32_t SERIALDELAY_4B;      // Four Byte Delay Time, calculated on startup.
uint8_t intro_pkts[] = {0x4D,0x33,0x5A};    // M3Z | Ident info serial mouse.

/* ---------------------------------------------------------- */
// Some structs for mouse tracking

typedef struct {                            // Mouse report information
    bool left, middle, right;
    int16_t  x, y, wheel;
    bool update;
} MOUSE_PKT;

typedef struct {                            // Mouse Settings and information
    uint8_t     speed;                      // Mouse Tracking Speed
    uint8_t     type;                       // Mouse Type
    uint8_t     pc_state;                   // CTS state tracker | taken from Aviancer's code since it was more straightforward than what I had already
    MOUSE_PKT   mpkt;                       // Current Mouse Packet
} MOUSE_DATA;

/* ---------------------------------------------------------- */
// Mouse Tracking Variables

MOUSE_DATA mouse_data;
static bool mouse_connected = false;    // Is mouse connected flag
bool btnFlipFlop[3];                    // The Button Flip Flop | Left Click + Middle Click + Right Click
bool btnUpdated[3];                     // FlipFlop Cycle Update Flag | Left Click + Middle Click + Right Click
bool btnToggle[3];                      // FlipFlop toggle flag | Left Click + Middle Click + Right Click
int16_t mLoc[3];                        // Mouse location Data | X + Y + Wheel

/*---------------------------------------*/
//           TinyUSB Functions           //
/*---------------------------------------*/

static void process_mouse_report(hid_mouse_report_t const * report);
void set_mouseclick(uint8_t spot, bool value);

// This is executed when a new device is mounted.
void tuh_hid_mount_cb(uint8_t dev_addr, uint8_t instance, uint8_t const* desc_report, uint16_t desc_len)
{
    uint8_t const itf_protocol = tuh_hid_interface_protocol(dev_addr, instance);

    if ( DEBUG ) { printf("Device with address %d, instance %d, protocol %d, has mounted.\r\n", dev_addr, instance, itf_protocol); }

    // If connected device is not a mouse or compatible
    if ( itf_protocol != HID_ITF_PROTOCOL_MOUSE ) {

        // Debug Print out
        if ( DEBUG) { printf("Device with address %d, instance %d is not a mouse.\r\n", dev_addr, instance); }

        // Call ALRT Code flasher for incompatible device. 
        // TODO

        return; // Exit func
    }

    gpio_put(LED_ALERT, 1);     // Turn on Alert LED
    mouse_connected = true;     // Flag mouse as connected

    if ( DEBUG ) { 
        const char* protocol_str[] = { "None", "Keyboard", "Mouse" };
        printf("Device with address %d, instance %d is a %s.\r\n", dev_addr, instance, protocol_str[itf_protocol]);
    }
}

// This is executed when a device is unmounted.
void tuh_hid_umount_cb(uint8_t dev_addr, uint8_t instance)
{   
    // DEBUG printout
    if ( DEBUG ) { printf("Device with address %d, instance %d was unmounted.\r\n", dev_addr, instance); }

    if ( mouse_connected ) {        // IF a mouse was previously connected
        gpio_put(LED_ALERT, 0);     // Turn off Alert LED
        mouse_connected = false;    // Flag mouse as not connected
    }

    //uart_deinit(UART_ID);           // DeInit UART for sanity sake
    //machine_reboot();               // There's a bug in TinyUSB, a reboot should bypass it
}

// This is executed when data is received from the mouse.
void tuh_hid_report_received_cb(uint8_t dev_addr, uint8_t instance, uint8_t const* report, uint16_t len)
{   
    // This is to ensure that anything which isn't a mouse is ignored
    if ( tuh_hid_interface_protocol(dev_addr, instance) == HID_ITF_PROTOCOL_MOUSE ) {
        process_mouse_report((hid_mouse_report_t const*) report);
    }
}

/*---------------------------------------*/
//            Mouse Processing           //
/*---------------------------------------*/

// Point the mouse report data to the correct places
static void process_mouse_report(hid_mouse_report_t const * report)
{
    // Send the button report data off to the flip flop tracker
    set_mouseclick(0, report->buttons & MOUSE_BUTTON_LEFT);
    set_mouseclick(2, report->buttons & MOUSE_BUTTON_RIGHT);

    // Limiting the max motion of a mouse movement axis helps prevent an overflow on the serial side of things 
    mLoc[0] = constrain( (mLoc[0] + report->x) , -127, 127);    // Process the X axis
    mLoc[1] = constrain( (mLoc[1] + report->y) , -127, 127);    // Process the Y axis

    if ( mouse_data.type == WHEELBTN ){
        set_mouseclick(1, report->buttons & MOUSE_BUTTON_MIDDLE);
        mLoc[2] = constrain( (mLoc[2] + report->pan) , -15, 15);
    } 
    else if ( mouse_data.type == THREEBTN ){
        set_mouseclick(1, report->buttons & MOUSE_BUTTON_MIDDLE);
    }
}

// Reset mouse state for the next cycle
void reset_cycle()
{
    for( u_short i=0; i<=2; i++ ){
        btnUpdated[i] = false;              // Reset update counter to False

        // If the toggle flag has been set, toggle the value of the flip-flop
        // Note:
        //      This would happen if the user clicked and let go during the same cycle. 
        if ( btnToggle[i] )
        {
            btnFlipFlop[i] = !(btnFlipFlop[i]);

            btnToggle[i] = false;   // Reset toggle flag
            btnUpdated[i] = true;   // Flag Button State as updated
        }
        mLoc[i] = 0;                // Reset mLoc array
    }
}

// Mouse values from TinyUSB are sent here
void set_mouseclick(uint8_t spot, bool value)
{      
    // If the value has not been updated during this cycle, accept value and toggle the FlipFlop Cycle Update Flag
    if ( !btnUpdated[spot] )
    {
        btnFlipFlop[spot] = value;
        btnUpdated[spot] = true;
    }
    else        // If the FlipFlop Cycle Update Flag have been set
    {
        if      ( value && !btnFlipFlop[spot] ) { btnFlipFlop[spot] = value; }  // If value is true and the FlipFlop is false, prioritize a click over a non click
        else if ( !value && btnFlipFlop[spot] ) { btnToggle[spot] = true; }     // if value is false, flag flip-flop for toggling on the next cycle
    }
}

// Update stored mouse packet
void update_mousepacket()
{
    MOUSE_PKT retpkt;

    // Dump in the current mouse data
    retpkt.left =   btnFlipFlop[0];
    retpkt.middle = btnFlipFlop[1];
    retpkt.right =  btnFlipFlop[2];
    retpkt.wheel =  mLoc[2];
    retpkt.update = false;

    // Limit mouse xy travel rate if required
    if      ( mouse_data.speed == SPEED75 ) { retpkt.x = travel_limit75(mLoc[0]); retpkt.y = travel_limit75(mLoc[1]); }
    else if ( mouse_data.speed == SPEED50 ) { retpkt.x = travel_limit50(mLoc[0]); retpkt.y = travel_limit50(mLoc[1]); }
    else if ( mouse_data.speed == SPEED25 ) { retpkt.x = travel_limit25(mLoc[0]); retpkt.y = travel_limit25(mLoc[1]); }
    else                                    { retpkt.x = mLoc[0]; retpkt.y = mLoc[1]; }

    // If an update is required from a previous cycle, IE a button has been let go of.
    for ( u_short i=0; i<=2; i++ ) { if ( btnUpdated[i] == true ) { retpkt.update = true; } }

    if ( !retpkt.update )
    {
        if      ( mouse_data.mpkt.left && !(retpkt.left) )              { retpkt.update = true; }
        else if ( mouse_data.mpkt.middle && !(retpkt.middle) )          { retpkt.update = true; }
        else if ( mouse_data.mpkt.right && !(retpkt.right) )            { retpkt.update = true; }
        else if ( retpkt.x != 0 || retpkt.y != 0 || retpkt.wheel != 0 ) { retpkt.update = true; }
    }

    reset_cycle();              // Prepare for the next cycle
    mouse_data.mpkt = retpkt;   // Overwrite previous mouse packet
}

/*---------------------------------------*/
//             SERIAL STUFF              //
/*---------------------------------------*/

// Post off data over UART. 
void serial_putc(uint8_t *buffer, int size){ 
    for( uint8_t i=0; i <= size; i++ )  { uart_putc_raw( UART_ID, buffer[i] ); } 
}

// Serial mouse negotiation
void mouse_id_nego() {
    /*---------------------------------------*/
    //        Serial Mouse negotiation       //
    /*---------------------------------------*/
    // Byte1:Always M                        //
    // Byte2:[None]=MS 3=Logitech Z=MSWheel  // 
    /*---------------------------------------*/

    // Wait for UART to be writable
    while ( !uart_is_writable ) { sleep_us(SERIALDELAY_1B); }   

    uart_putc_raw( UART_ID, intro_pkts[0] );        // M
    
    if ( mouse_data.type == THREEBTN ) {
        sleep_us(SERIALDELAY_1B);           
        uart_putc_raw( UART_ID, intro_pkts[1] );    // 3
    }
    else if ( mouse_data.type == WHEELBTN ) {
        sleep_us(SERIALDELAY_1B);       
        uart_putc_raw( UART_ID, intro_pkts[2] );    // Z
    }

    sleep_us( SERIALDELAY_1B );                     // Wait for packet to send              
}

// Update stored mouse data and post
void post_serial_mouse() {

    uint8_t packet[4];                          // Create packet array
    update_mousepacket();                       // Get Current Mouse Data
    if ( !mouse_data.mpkt.update ) { return; }  // Skip if no update.

    packet[0] = ( 0x40 | (mouse_data.mpkt.left ? 0x20 : 0) | (mouse_data.mpkt.right ? 0x10 : 0) | ((mouse_data.mpkt.y >> 4) & 0xC) | ((mouse_data.mpkt.x >> 6) & 0x3));
    packet[1] = ( 0x00 | (mouse_data.mpkt.x & 0x3F)); 
    packet[2] = ( 0x00 | (mouse_data.mpkt.y & 0x3F));

    if ( mouse_data.type == WHEELBTN ){         // Add Wheel Data + Third Button
        packet[3] = (0x00 | (mouse_data.mpkt.middle ? 0x20 : 0) | (-mouse_data.mpkt.wheel & 0x0f));
        serial_putc(packet,  3);
    }
    else if ( mouse_data.type == THREEBTN ){    // Add Third Button
        packet[3] = (0x00 | (mouse_data.mpkt.middle ? 0x20 : 0));
        serial_putc(packet,  3);
    }
    else{
        serial_putc(packet,  2);
    }
}

/*---------------------------------------*/
//          Mouse Settings Stuff         //
/*---------------------------------------*/

/*
::TODO::
I do want to have mouse type hot changeable but I just have to sit and experiment with it. 
Hitting reset it fine for now
*/

// Sets Mouse Speed from the headers.
void setMouseType()
{   
    if      ( !gpio_get(MO_WHEEL) )     { mouse_data.type = WHEELBTN; }
    else if ( !gpio_get(MO_THREEBTN) )  { mouse_data.type = THREEBTN; }
    else                                { mouse_data.type = TWOBTN; }
}

// Updates Mouse Travel Rate Divider from the headers.
void setMouseSpeed()
{   
    if      ( !gpio_get(MO_75SPEED) && !gpio_get(MO_50SPEED) )  { mouse_data.speed = SPEED25; }
    else if ( !gpio_get(MO_50SPEED) )                           { mouse_data.speed = SPEED50; }
    else if ( !gpio_get(MO_75SPEED) )                           { mouse_data.speed = SPEED75; }
    else                                                        { mouse_data.speed = SPEED100; }
}

/*
I spent a bit of time trying to figure out the simplest way to have mouse settings updatable without restarting the pi pico.
I could have just called setMouseSpeed() in the main loop all the time but that felt wasteful.
Debounce in a gpio_callback doesn't work well, give it a Google, some fellow tried it and it was spotty.
I implemented a hardware debounce but decided against it, since it made the final PCB bigger for something not integral. 

Ultimately I decided it was best to add an alarm from a GPIO callback to act as a shitty debounce.
While the IRQ is triggering from the bounce the mouse movement could be spotty but you're not moving the mouse while changing pin headers, so it doesn't matter.
Plus, I want as little as possible in the main loop to avoid the possibility of missing input.
*/

/* ===== Mouse Options Callback ===== */

volatile bool MO_IRQ_TRIGGERED = false;

int64_t MO_alarm_callback(alarm_id_t id, void *user_data)
{
    setMouseSpeed();                          // Update Mouse Options
    MO_IRQ_TRIGGERED = false;                   // Unset IRQ Bool
    return 0;                                   // Ret 0
}

void MO_gpio_callback(uint gpio, uint32_t events) 
{
    gpio_acknowledge_irq(gpio, events);         // ACK GPIO IRQ
    if ( !MO_IRQ_TRIGGERED )                    // If IRQ bool is not set
        MO_IRQ_TRIGGERED = true;                // Set IRQ bool
        add_alarm_in_ms(2000, MO_alarm_callback, NULL, true);   // Call MO_alarm_callback in 2 seconds
}

/* ===== Stop Bit Callback ===== */
// Made this seperate since I don't want to touch the UART settings unless required.
volatile bool SB_IRQ_TRIGGERED = false;

int64_t SB_alarm_callback(alarm_id_t id, void *user_data)
{
    // Set Double Stop Toggle
    if ( !gpio_get(MO_7N2) )    { uart_set_format(UART_ID, 7, 2, UART_PARITY_NONE); }   // 7N2
    else                        { uart_set_format(UART_ID, 7, 1, UART_PARITY_NONE); }   // 7N1
    SB_IRQ_TRIGGERED = false;                   // Unset IRQ Bool
    return 0;                                   // Ret 0
}

void SB_gpio_callback(uint gpio, uint32_t events) 
{
    gpio_acknowledge_irq(gpio, events);         // ACK GPIO IRQ
    if ( !SB_IRQ_TRIGGERED )                    // If IRQ bool is not set
        SB_IRQ_TRIGGERED = true;                // Set IRQ bool
        // Call SB_alarm_callback in 2 seconds
        add_alarm_in_ms(2000, SB_alarm_callback, NULL, true);
}


/*---------------------------------------*/
//             Repeating Timer           //
/*---------------------------------------*/
struct repeating_timer serial_timer;
bool serial_timer_running = false;

bool serial_timer_callback(struct repeating_timer *t) {
    
    if ( mouse_data.pc_state == CTS_TOGGLED && mouse_connected ) { post_serial_mouse(); }
    return true;
}

bool create_serial_timer(int64_t delay_ms) {
    add_repeating_timer_us(delay_ms, serial_timer_callback, NULL, &serial_timer);
    return true;
}

bool delete_serial_timer() {

    bool cancelled = false;

    while ( !cancelled ) {
        cancel_repeating_timer(&serial_timer);
        sleep_us(SERIALDELAY_1B);
    }

    return false;
}
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

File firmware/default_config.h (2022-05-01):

#include <stdbool.h>

/*---------------------------------------*/
//                 DEBUG                 //
/*---------------------------------------*/

// All this really does is give printf's out via UART0
#define DEBUG false          // Debug Flag for things


/*---------------------------------------*/
//                GPIO PINS              //
/*---------------------------------------*/

// DIP Switch Pins
#define DIPSW_THREEBTN 9        // Dip Switch 1 | LOGITECH
#define DIPSW_WHEEL 10          // Dip Switch 2 | MS Wheel
#define DIPSW_75XYSPEED 11      // Dip Switch 3 | 75% speed | Dip 3 + 4 depressed will set mouse speed to 25%
#define DIPSW_50XYSPEED 12      // Dip Switch 4 | 50% speed | Dip 3 + 4 depressed will set mouse speed to 25%
#define DIPSW_7N2 13            // Dip Switch 5 | 7N2 format
#define DIPSW_19200 14          // Dip Switch 6 | High Buad Rate

// LEDS 
#define LED_PWR 2
#define LED_ALERT 3

//UART stuff
#define UART_ID uart1       // Use UART1, keep UART0 for DEBUG printing
#define UART_TX_PIN 4       // UART1 TX --> MAX232 pin 11
#define UART_RX_PIN 5       // UART1 RX --> MAX232 pin 12
#define UART_CTS_PIN 6      // CTS      --> MAX232 pin 9
#define UART_RTS_PIN 7      // RTS      --> MAX232 pin 10


#define RESET_FLASH 17      // Button for resetting the stored settings back to default, defined below.


/*---------------------------------------*/
//            Settings Defaults          //
/*---------------------------------------*/
// These are used until they are changed via software for dipswitches

// global limit | Range 1 -> 200
static uint8_t default_xytravel_percentage = 100;

// seperate x and y limits. | Range 1 -> 200
static uint8_t default_xtravel_percentage = 100;
static uint8_t default_ytravel_percentage = 100;

// TWOBTN = 0 | THREEBTN = 1 | WHEELBTN = 2 
static int8_t default_mousetype = 0;

// Double Stop Bit
// 7N1 = false | 7N2 = true
static bool default_doublestopbit = false;

// Baud Rate
/* ---------- Acceptible baud rates ----------
        1200 | 2400 | 4800 | 9600 | 19200
            Recommended value is 1200 

Any values outside of the ones above, are rejected
and the default value of 1200 is used.

Note:
As far as I can see from docs, serial mice ran at
1200 Baud, so you will need modified drivers for higher baud rates
   ------------------------------------------ */

static uint16_t default_baudrate = 1200;

// Swap left and right mouse buttons
// Could be handy for left handed people.
static bool default_swap_left_right = false;

// Uses the forward and back buttons of a mouse as alturnative left and right mouse buttons. 
// The forward and back butons are on the side of the mouse and usually act as the page forward and backwards in file and web browsers. 
// Forward button -> left click | Back Button -> right click
static bool default_use_forward_backward = false;

// Changes above to 
// Forward button -> right click | Back Button -> left click
static bool default_swap_forward_backward = false;

// Invert X axis (Left and Right movement)
static bool default_invert_x = false;

// Invert Y axis (Up and Down movement)
static bool default_invert_y = false;

// Added version 1.1.X
/*
/==-- USB mice communicate with the pico faster than the pico communicates with the serial port. 
/==-- Movement type determines what is done wit the extra packets of data. 
/==-- Note: Applies only to X and Y mouse movement
/==--
/==-- ADDITIVE:
/==--       Adds up the mouse movement and sends it off in the next serial packet. 
/==--       Results in a very sensitive feeling mouse, sometimes too sensitive  and that's where Averaging comes in.
/==--
/==-- AVERAGE:
/==--       Finds the average change in mouse movement and sends that off in the next serial packet.
/==--       Results in a fairly insensitive  feeling mouse, could be useful for a higher DPI mouse or personal preference.
/==--
/==-- COAST:
/==--       Unlike Additive and Average; Coast does not throw away extra movement when the mouse is moved quickly, instead it incrementally sends out the movement. 
/==--       Results in a cursor feeling like it's skidding along on ice at high speeds. I don't know where it would be useful but it's fun to mess with!
/==-- 0 -> Additive axis movement | 1 -> Average axis movement | 2-> Coast
*/
static uint8_t default_mouse_movt_type = 0;

/*
/==-- COSINE SMOOTHING 
/==-- Makes the cursor proportionally less sensitive  at high speeds, leaving the movement mostly one to one at low speeds. 
/==-- This was added as an attempt to mitigate the problem of the much more sensitive  optical mouse overshooting icons on a low res screen. 
/==-- It could be useful for point and click DOS games but is not recommended for games where mouse movement controls a camera.
/==-- 0 -> Disabled | 1 -> Low | 2 -> Medium | 3 -> High | 4 - > Very High
*/
static uint8_t default_use_cosine_smoothing = 0;
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

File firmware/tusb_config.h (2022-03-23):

#ifndef _TUSB_CONFIG_H_
#define _TUSB_CONFIG_H_

#ifdef __cplusplus
 extern "C" {
#endif

//--------------------------------------------------------------------
// COMMON CONFIGURATION
//--------------------------------------------------------------------

// defined by compiler flags for flexibility
#ifndef CFG_TUSB_MCU
  #error CFG_TUSB_MCU must be defined
#endif


// RHPort max operational speed can defined by board.mk
// Default to Highspeed for MCU with internal HighSpeed PHY (can be port specific), otherwise FullSpeed
#ifndef BOARD_HOST_RHPORT_SPEED
  #if TU_CHECK_MCU(OPT_MCU_LPC18XX, OPT_MCU_LPC43XX, OPT_MCU_MIMXRT10XX, OPT_MCU_NUC505) ||\
      TU_CHECK_MCU(OPT_MCU_CXD56, OPT_MCU_SAMX7X, OPT_MCU_BCM2711) ||\
      TU_CHECK_MCU(OPT_MCU_FT90X, OPT_MCU_FT93X)
    #define BOARD_HOST_RHPORT_SPEED   OPT_MODE_HIGH_SPEED
  #else
    #define BOARD_HOST_RHPORT_SPEED   OPT_MODE_FULL_SPEED
  #endif
#endif

// Device mode with rhport and speed defined by board.mk
#if   BOARD_HOST_RHPORT_NUM == 0
  #define CFG_TUSB_RHPORT0_MODE     (OPT_MODE_HOST | BOARD_HOST_RHPORT_SPEED)
#elif BOARD_HOST_RHPORT_NUM == 1
  #define CFG_TUSB_RHPORT1_MODE     (OPT_MODE_HOST | BOARD_HOST_RHPORT_SPEED)
#else
  #error "Incorrect RHPort configuration"
#endif

#ifndef CFG_TUSB_OS
#define CFG_TUSB_OS                 OPT_OS_NONE
#endif

// CFG_TUSB_DEBUG is defined by compiler in DEBUG build
// #define CFG_TUSB_DEBUG           0

/* USB DMA on some MCUs can only access a specific SRAM region with restriction on alignment.
 * Tinyusb use follows macros to declare transferring memory so that they can be put
 * into those specific section.
 * e.g
 * - CFG_TUSB_MEM SECTION : __attribute__ (( section(".usb_ram") ))
 * - CFG_TUSB_MEM_ALIGN   : __attribute__ ((aligned(4)))
 */
#ifndef CFG_TUSB_MEM_SECTION
#define CFG_TUSB_MEM_SECTION
#endif

#ifndef CFG_TUSB_MEM_ALIGN
#define CFG_TUSB_MEM_ALIGN          __attribute__ ((aligned(32)))
#endif

//--------------------------------------------------------------------
// DEVICE CONFIGURATION
//--------------------------------------------------------------------

#ifndef CFG_TUD_ENDPOINT0_SIZE
#define CFG_TUD_ENDPOINT0_SIZE    64
#endif

//--------------------------------------------------------------------
// HOST CONFIGURATION
//--------------------------------------------------------------------

// Size of buffer to hold descriptors and other data used for enumeration
#define CFG_TUH_ENUMERATION_BUFSIZE 256

#define CFG_TUH_HUB                 4 // Number of Hubs chained
#define CFG_TUH_CDC                 0 // Virtual Com I think
#define CFG_TUH_MSC                 0 // Mass Storage
#define CFG_TUH_VENDOR              0 // Just fucking broken

#define CFG_TUSB_HOST_DEVICE_MAX    (CFG_TUH_HUB ? 4 : 1) // normal hub has 4 ports

//------------- HID -------------//
#define CFG_TUH_HID                 4
#define CFG_TUH_HID_EPIN_BUFSIZE    64
#define CFG_TUH_HID_EPOUT_BUFSIZE   64

#ifdef __cplusplus
 }
#endif

#endif /* _TUSB_CONFIG_H_ */

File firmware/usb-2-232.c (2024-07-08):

#include "tusb.h"
#include <stdio.h>
#include "pico/stdlib.h"
#include "hardware/gpio.h"
#include "hardware/uart.h"
#include "hardware/timer.h"
#include "pico/multicore.h"

// Needed to account for update in tinyUSB
#if __has_include("bsp/board_api.h")
#include "bsp/board_api.h"
#else
#include "bsp/board.h"
#endif

#include "include/utils.h"
#include "include/core_1.h"
#include "include/ctypes.h"
#include "include/serial.h"
#include "include/version.h"
#include "include/hid_app.h"

#include "default_config.h"

/* ---------------------------------------------------------- */
// Mouse Tracking Variables

MOUSE_DATA mouse_data;

// Aggregate movements before sending
CFG_TUSB_MEM_SECTION static hid_mouse_report_t usb_mouse_report_prev;

static absolute_time_t usb_polling_target;


/*---------------------------------------*/
//                  Main                 //
/*---------------------------------------*/
int main(){

    // Mild underclock
    set_sys_clock_khz(125000, true);

    // If we're using an updated version of TinyUSB then enable the scrollwheel
    #if __has_include("bsp/board_api.h")
      tuh_hid_set_default_protocol(HID_PROTOCOL_REPORT);
    #endif
    
    stdio_init_all();           // pico SDK
    board_init();               // init board from TinyUSB
    tusb_init();                // init TinyUSB

    /*---------------------------------------*/
    //                 LEDS                  //
    /*---------------------------------------*/

    init_led(LED_PWR);          // Init Power LED
    gpio_put(LED_PWR, 1);       // Turn on Power LED
    init_led(LED_ALERT);        // Init Alert LED

    /*---------------------------------------*/
    //            Reset the flash            //
    /*---------------------------------------*/

    // Init the reset pin
    init_pinheader(RESET_FLASH);  
    sleep_us(500);         // wait a bit to avoid false postitive

    // If the reset pin is closed on startup
    if ( !gpio_get(RESET_FLASH) ) {   

      board_led_write(1);     // Turn on Built in LED for feedback
      sleep_ms(3000);         // Wait for 3 seconds.
      
      // IF reset pin is still held
      if ( !gpio_get(RESET_FLASH) ) {   
          
        loadPersistentSetDefaults();    // Load the default Settings
        savePersistentSet();            // Save the default settings

        // Blink built-in LED forever waiting for user to reboot device
        while(1) {   
          board_led_write(0);   
          sleep_ms(800);
          board_led_write(1); 
          sleep_ms(800);
        }

      } else {
        board_led_write(0);     // Turn off Built in LED
      }
    }
    
    /*---------------------------------------*/
    //              Mouse Options            //
    /*---------------------------------------*/
    
    // Setup Dip Switch Pins
    int dipswpins[6] = { DIPSW_THREEBTN, DIPSW_WHEEL, DIPSW_75XYSPEED, DIPSW_50XYSPEED, DIPSW_7N2, DIPSW_19200 };
    for ( uint8_t i = 0; i < 6; i++ ) { 
        
      init_pinheader(dipswpins[i]);           // init Dip Switch Pins
      
      sleep_us(20000);                        // Wait a bit to avoid false postitive

      // Set up IRQ callbacks on Dip Switch Pins
      gpio_set_irq_enabled_with_callback(dipswpins[i], GPIO_IRQ_EDGE_RISE | GPIO_IRQ_EDGE_FALL, true, &dipswGPIOCallback);
      }

    initPersistentSet();        // try to load persistent settings.
    
    /*---------------------------------------*/
    //              UART STUFF               //
    /*---------------------------------------*/

    /* ----- UART SETUP ----- */
    // ==================================================

    gpio_set_function(UART_TX_PIN, GPIO_FUNC_UART); // Set the TX pins
    gpio_set_function(UART_RX_PIN, GPIO_FUNC_UART); // Set the RX pins

    gpio_init(UART_CTS_PIN);                        // CTS Pin
    gpio_set_dir(UART_CTS_PIN, GPIO_IN);            // CTS Pin direction

    init_serial_uart(7);         // Init our uart
    calcSerialDelay();

    start_core1(0);

    /*----------   TIMERS   ----------*/
    startTerminalTimer();               // Start Our Terminal Timer

    /*---------------------------------------*/
    //               Main Loop               //
    /*---------------------------------------*/
    while(1)
    {  
        /*----------   Blink Built in LED to show the main loop is running   ----------*/
        // Blink the built in LED when in DEBUG Mode
        #if DEBUG > 0
        blink_led_task();
        #endif
        
        /*---------- Core 1 talking to Core 0 ----------*/
        if ( multicore_fifo_rvalid() )
        {
          switch ( multicore_fifo_pop_blocking() )
          {
            case cf_update:
            
              // Update the mouse packet from Core0 so Core1 can pull the correct data
              update_mousepacket();

              // Wait for fifo to be writable
              while ( !multicore_fifo_wready() ) { tight_loop_contents(); } 

              // Reply to Core1
              multicore_fifo_push_blocking( mouse_data.mpkt.update ? cf_post : cf_nopost );

            break;
          }
        }

        /*----------   Serial Terminal   ----------*/
        // Serial State is used to say if the pico should be a serial terminal or a mouse. 
        if ( mouse_data.serial_state == 1  || mouse_data.serial_state == 2 )
        {   
          stop_core1();                   // Stop Core 1 to stop it fecking up the nand flash
          startPWRBlinkerTimer();         // Blink the PWR led 

          // If the UART we got data from is the one we're using for the mouse
          if ( ( mouse_data.serial_state == 1 && UART_ID == uart0 ) || ( mouse_data.serial_state == 2 && UART_ID == uart1 ) ) {
            serial_terminal(UART_ID,  (10000 / (int) ( mouse_data.realbaudrate / 1200 )) );  

          } else {  // Else the user connected a TTL to the unused uart
              serial_terminal(mouse_data.serial_state == 1 ? uart0 : uart1, 1500);  // 10000 / (115200 / 1200 ) ~= 105 
          }

          stopPWRBlinkerTimer();          // Stop Blinking the PWR LED
          gpio_put(LED_PWR, 1);           // Turn on PWR LED
          mouse_data.serial_state = 0;    // Set serial State to mouse mode
          start_core1(0);                 // Resume Core 1
          startTerminalTimer();           // Resume Terminal Timer
        }


        // USB Mouse Polling
        // -----------------------------
        // TinyUSB support USB polling rates up to 1000hz
        // However
        // AVG movement @1000hz feels very very wrong. 
        // Adding these delays for the AVG movement is acting as a sort of handicap on the USB polling rate
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

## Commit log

2021-11-15 KiCad Files Upload
    [USBtoserialpico.kicad_pcb, USBtoserialpico.sch]
2021-11-15 fixed some small mistakes in the pcb
    I forgot to give the max232 a connection to ground.
    [USBtoserialpico.kicad_pcb, USBtoserialpico.sch]
2021-11-17 Updated KiCad Files
    [BOM_JLCSMT.xls, USB-2-232.kicad_pcb, USB-2-232.sch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]
2021-12-31 PCBv2
    Fixed the silkscreen for J1 and fixed the crossed traces on serial connector.
    Moved some traces around to make it look nicer and changed the PFP logo so hopefully JLC can't feck it up.
    [USB-2-232-USB-2-232Pcb_1509.stl, USB-2-232.kicad_pcb, USB-2-232.sch]
2021-12-31 PCB images
    turns out github doesn't like webp for no reason
2022-01-01 slimline PCB
    Made as an answer to people asking for this project without dipswitches. I decided to remove the usb pin header and the serial pin header while I was at it.
    [BOM_JLCSMT.xls, USB-2-232-USB-2-232Pcb_1509.stl, USB-2-232-slim.kicad_pcb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]
2022-01-01 moved phat pcb images
2022-01-01 Fixed misplaced silkscreen
    [USB-2-232-slim.kicad_pcb]
2022-01-14 external case update
2022-01-15 Internal phat case
    [Case-Internal-Lid.stl, Case-Internal-Sled.stl]
2022-07-24 Modified Drivers added
    Compiled from source
2024-06-09 Added LCSC BOM and updated README.md
    [BOM_LCSC.xls]
2024-06-24 added 3/5v bridging instructions
2024-06-25 Added modified Windows 9x serial mouse drivers
    read the readme's thanks.
2024-06-26 "power only" USB cable note. removed hard coding of Pico SDK location
2024-07-03 Fix wheel mouse 3rd button bit
    [serial.c]
2024-08-07 more Drivers
    Added more drivers, MS-Dos, Win3.1, intellipoint and another version of win98se, I've included the Byte location of the serial latch divisor where possible.
